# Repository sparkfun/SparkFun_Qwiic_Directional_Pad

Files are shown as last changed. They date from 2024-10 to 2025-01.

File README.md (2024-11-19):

SparkFun Qwiic Directional Pad
========================================

SparkFun Qwiic Directional Pad (https://www.sparkfun.com/products/26851)

[*SparkFun Qwiic Directional Pad (PRT-26851)*](https://www.sparkfun.com/products/26851)

<Basic description of the part.>

Repository Contents
-------------------

* **.github/workflows** - YAML files used for GitHub Actions and GitHub Pages/mkdocs
* **/Firmware** - Example code
* **/Hardware** - KiCad design files (.kicad_pcb, .kicad_sch, .kicad_pro)
* **/docs** - Online documentation files
  * **/assets** - Folder containing all the file assets used for product documentation
    * **/3d_model** - Exported 3D models from KiCad
    * **/board_files** - Copy of design files used for product documentation
    * **/component_documentation** - Datasheets and manuals for hardware components
    * **/img** - Images for product documentation
  * **/github** - Files stating how to contribute and filing issues used for product documentation
  * **/javascript** - Folder containing custom javascript used for product documentation
  * **/stylesheet** - Folder containing CSS files used for product documentation
* **/overrides** - Customization files used for product documentation
  * **/.icons** - Icons used for GitHub used for product documentation
  * **./partials** - Used for product documentation

Documentation
--------------
* **[Library](https://github.com/sparkfun/SparkFun_I2C_Expander_Arduino_Library)** - Arduino library for the Qwiic Directional Pad.
* **[Hookup Guide](https://docs.sparkfun.com/SparkFun_Qwiic_Directional_Pad/)** - Basic hookup guide for the Qwiic Directional Pad.

Product Versions
----------------
* [PRT-26851](https://www.sparkfun.com/products/26851) - v1.1

Version History
---------------
* v1.1 - Initial Release

License Information
-------------------

This product is _**open source**_! 

Please review the LICENSE.md file for license information. 

If you have any questions or concerns on licensing, please contact technical support on our [SparkFun forums](https://forum.sparkfun.com/viewforum.php?f=152).

Distributed as-is; no warranty is given.

- Your friends at SparkFun.

_<COLLABORATION CREDIT>_

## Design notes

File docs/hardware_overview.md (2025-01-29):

In this section, we will highlight the hardware and pins that are broken out on the SparkFun Qwiic Directional Pad. For more information, check out our [Resources and Going Further](../resources/) on the components used on the breakout board.

<div style="text-align: center;">
  <table>
    <tr style="vertical-align:middle;">
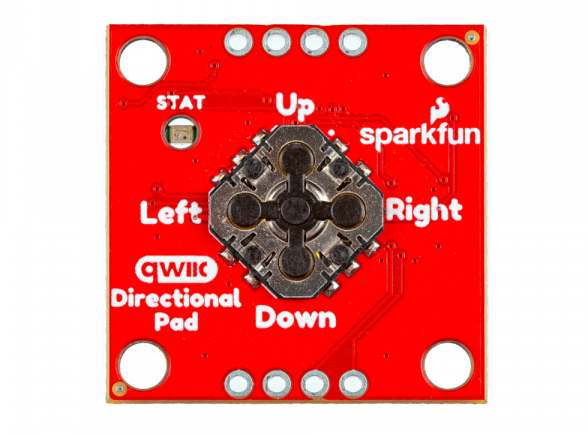
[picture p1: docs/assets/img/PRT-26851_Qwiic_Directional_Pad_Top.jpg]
Top View
     <td style="text-align: center; vertical-align: middle; border: solid 1px #cccccc;"></td>
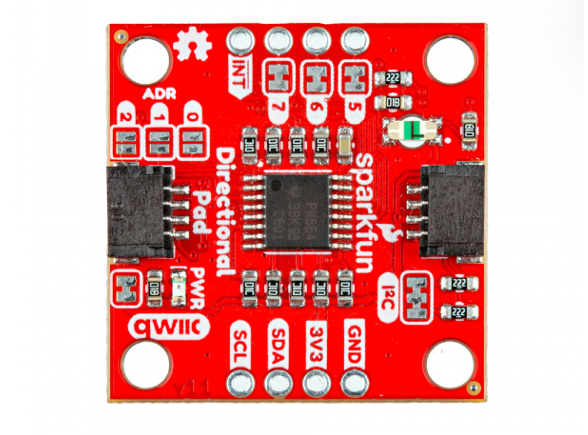
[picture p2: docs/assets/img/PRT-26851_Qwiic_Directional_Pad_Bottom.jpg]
Bottom View
     <td style="text-align: center; vertical-align: middle; border: solid 1px #cccccc;"></td>
    </tr>
    <tr style="vertical-align:middle;">
     <td style="text-align: center; vertical-align: middle; border: solid 1px #cccccc;"><i>Top View</i></td>
     <td style="text-align: center; vertical-align: middle; border: solid 1px #cccccc;"><i>Bottom View</i></td>
    </tr>
  </table>
</div>

### Power

To power the board, you will need **3.3V**. You can connect a Qwiic cable to the Qwiic connector on either side of the board or you can solder directly to the PTHs. Below are the power pins that are broken out on the edge of the board.

* **3V3** &mdash; This pin is the voltage input for the board. The recommended input voltage for this pin is 3.3V.
* **GND** &mdash; Of course, is the common, ground voltage (0V reference) for the system.

<div style="text-align: center;">
  <table>
    <tr style="vertical-align:middle;">
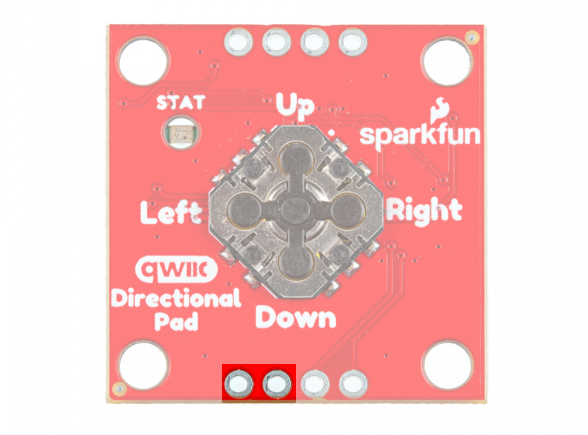
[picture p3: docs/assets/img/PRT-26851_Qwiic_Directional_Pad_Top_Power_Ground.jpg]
Power and Ground Highlighted - Top View
      <td style="text-align: center; vertical-align: middle; border: solid 1px #cccccc;"></td>
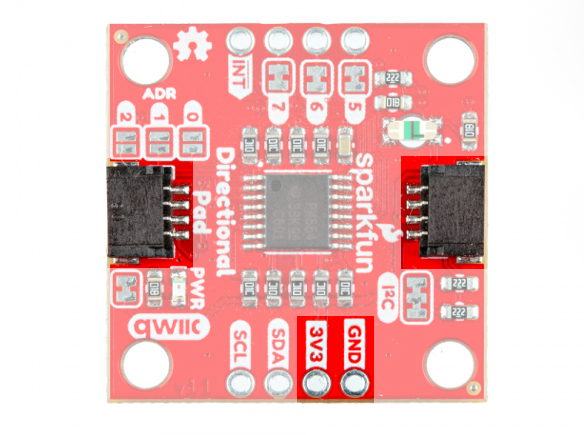
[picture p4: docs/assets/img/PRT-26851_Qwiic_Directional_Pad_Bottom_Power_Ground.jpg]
Power, Ground, and Qwiic Connector Highlighted - Bottom View
     <td style="text-align: center; vertical-align: middle; border: solid 1px #cccccc;"></td>
    </tr>
    <tr style="vertical-align:middle;">
      <td style="text-align: center; vertical-align: middle; border: solid 1px #cccccc;"><i>Power and Ground Highlighted - Top View</i></td>
     <td style="text-align: center; vertical-align: middle; border: solid 1px #cccccc;"><i>Power, Ground, and Qwiic Connector Highlighted - Bottom View</i></td>
    </tr>
  </table>
</div>

### 5-Way Directional Pad

A low profile 5-way directional pad is populated on the top side of the board. These buttons are small! We recommend using your fingernail when pressing down on a button. Each pad includes a momentary push button that is read by the PCA9554 8-bit I<sup>2</sup>C I/O expander that is populated on the bottom of the board.

<div style="text-align: center;">
  <table>
    <tr style="vertical-align:middle;">
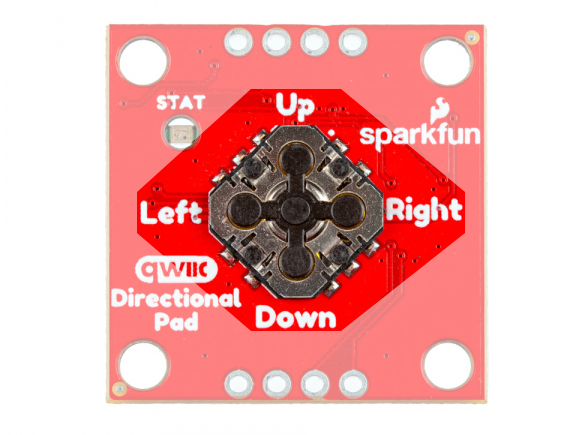
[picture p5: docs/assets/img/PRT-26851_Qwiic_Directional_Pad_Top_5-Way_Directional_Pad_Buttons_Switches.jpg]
5-Way Directional Pad Highlighted - Top View
      <td style="text-align: center; vertical-align: middle; border: solid 1px #cccccc;"></td>
    </tr>
    <tr style="vertical-align:middle;">
      <td style="text-align: center; vertical-align: middle; border: solid 1px #cccccc;"><i>5-Way Directional Pad Highlighted - Top View</i></td>
    </tr>
  </table>
</div>

!!! note
    We recommend pressing only one button at a time! For example, if the UP button is pressed down, it will register the UP button being pressed down first due to the way the condition statements are written in the Arduino code. Once the UP button is released, the board will be able to read another button press. However, if the LEFT button is pressed and then the UP button is pressed, the Qwiic Directional Pad will register the UP button.

### PCA9554 8-bit I<sup>2</sup>C I/O Expander

The TI PCA9554 that is populated on the bottom side of the board is an 8-bit I<sup>2</sup>C I/O expander that enables users to read and write to the following GPIO pins through I<sup>2</sup>C. It is used to read the 5-way directional pad or write to the non-addressable RGB LED. The I<sup>2</sup>C address of the PCA9554 is set to **0x20** by default. By adjusting the jumpers on the back of the board, the alternative address can be any value between _0x21_ to _0x27_.

* **GPIO0** &mdash; GPIO0 is connected to the 5-way directional pad's UP button. A 10k&ohm; pull-up resistor is connected.
* **GPIO1** &mdash; GPIO1 is connected to the 5-way directional pad's DOWN button. A 10k&ohm; pull-up resistor is connected.
* **GPIO2** &mdash; GPIO3 is connected to the 5-way directional pad's RIGHT button. A 10k&ohm; pull-up resistor is connected.
* **GPIO3** &mdash; GPIO4 is connected to the 5-way directional pad's LEFT button. A 10k&ohm; pull-up resistor is connected.
* **GPIO4** &mdash; GPIO4 is connected to the 5-way directional pad's CENTER button. A 10k&ohm; pull-up resistor is connected.
* **GPIO5** &mdash; GPIO5 is connected to the blue LED. The LED can be disconnected if users decide to use a different input to the GPIO5's PTH.
* **GPIO6** &mdash; GPIO6 is connected to the green LED. The LED can be disconnected if users decide to use a different input to the GPIO6's PTH.
* **GPIO7** &mdash; GPIO7 is connected to the red LED. The LED can be disconnected if users decide to use a different input to the GPIO7's PTH.

<div style="text-align: center;">
  <table>
    <tr style="vertical-align:middle;">
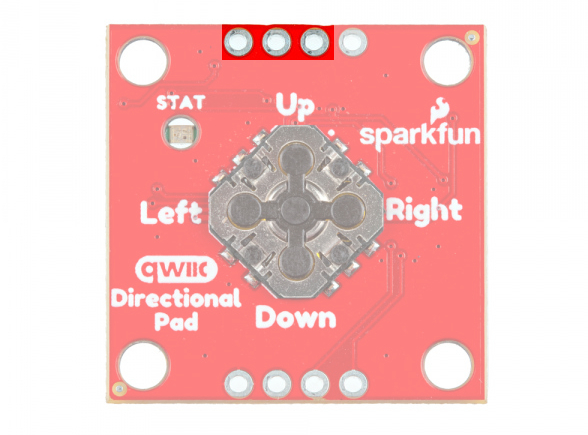
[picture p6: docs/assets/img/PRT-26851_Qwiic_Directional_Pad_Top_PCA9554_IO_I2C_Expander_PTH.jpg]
PCA9554 Highlighted - Top View
      <td style="text-align: center; vertical-align: middle; border: solid 1px #cccccc;"></td>
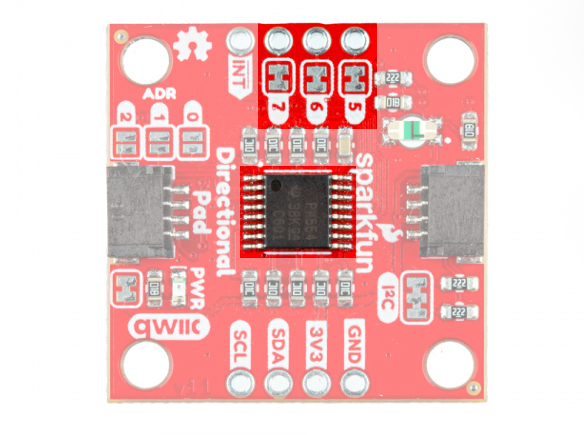
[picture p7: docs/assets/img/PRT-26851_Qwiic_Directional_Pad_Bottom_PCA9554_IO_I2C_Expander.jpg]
PCA9554 Highlighted - Bottom View
      <td style="text-align: center; vertical-align: middle; border: solid 1px #cccccc;"></td>
    </tr>
    <tr style="vertical-align:middle;">
     <td style="text-align: center; vertical-align: middle; border: solid 1px #cccccc;" colspan=2"><i>PCA9554 and Some GPIO Pins Highlighted<br />Top and Bottom View</i></td>
    </tr>
  </table>
</div>

### Qwiic and I<sup>2</sup>C

The board includes two horizontal Qwiic connectors to connect to other Qwiic-enabled I<sup>2</sup>C devices. However, the board still breaks out 0.1"-spaced pins for users who prefer a soldered connection.

* **SCL** &mdash; I<sup>2</sup>C clock on the PCA9554.
* **SDA** &mdash; I<sup>2</sup>C data on the PCA9554.

<div style="text-align: center;">
  <table>
    <tr style="vertical-align:middle;">
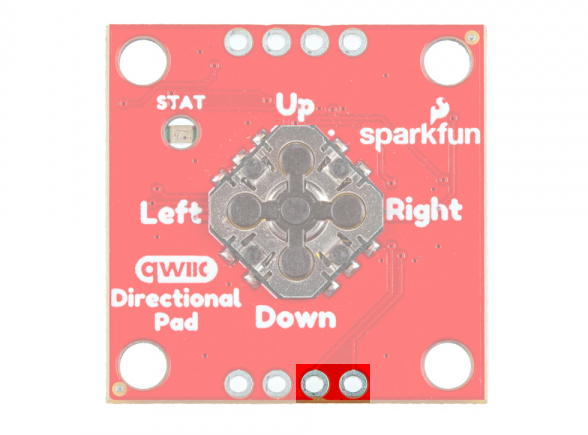
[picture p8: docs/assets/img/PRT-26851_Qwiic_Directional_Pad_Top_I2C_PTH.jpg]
Qwiic Connector, I2C, and PCA9554 Highlighted
     <td style="text-align: center; vertical-align: middle; border: solid 1px #cccccc;"></td>
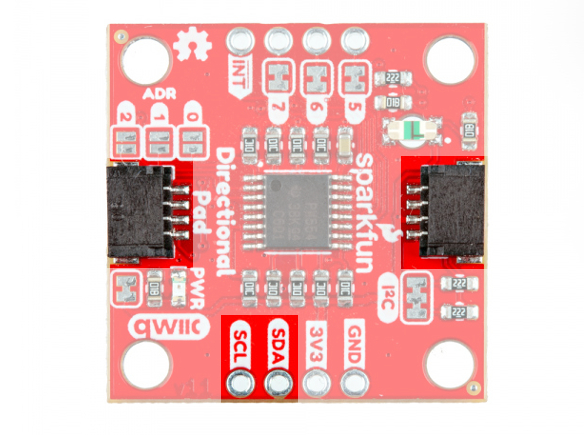
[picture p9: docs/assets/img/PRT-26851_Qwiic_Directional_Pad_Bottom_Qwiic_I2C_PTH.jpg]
Qwiic Connector, I2C, and PCA9554 Highlighted
     <td style="text-align: center; vertical-align: middle; border: solid 1px #cccccc;"></td>
    </tr>
    <tr style="vertical-align:middle;">
     <td style="text-align: center; vertical-align: middle; border: solid 1px #cccccc;"><i>Qwiic Connector, I<sup>2</sup>C, and PCA9554 Highlighted - Top View</i></td>
      <td style="text-align: center; vertical-align: middle; border: solid 1px #cccccc;"><i>I<sup>2</sup>C Highlighted - Bottom View</i></td>
    </tr>
  </table>
</div>

As explained in the previous section, the I<sup>2</sup>C address of the PCA9554 is set to **0x20** by default. By adjusting the jumpers on the back of the board, the alternative address can be any value between _0x21_ to _0x27_. Make sure to check the Jumpers section below for more information.

### Interrupt

The interrupt pin labeled as INT is for users that want to notify a microcontroller that there is a button being pressed down on the 5-way directional pad. This pin is active low.

<div style="text-align: center;">
  <table>
    <tr style="vertical-align:middle;">
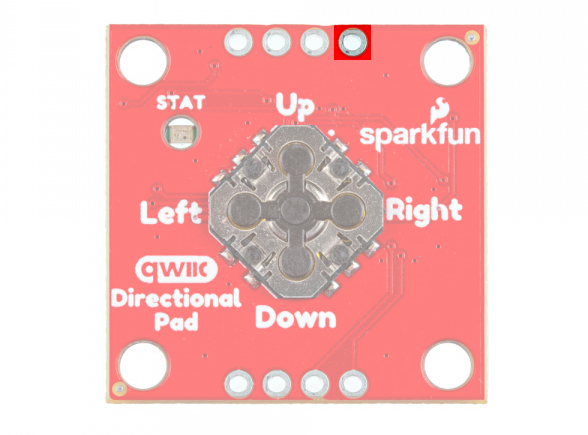
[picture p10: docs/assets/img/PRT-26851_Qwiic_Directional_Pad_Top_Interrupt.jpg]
Interrupt Highlighted - Top View
      <td style="text-align: center; vertical-align: middle; border: solid 1px #cccccc;"></td>
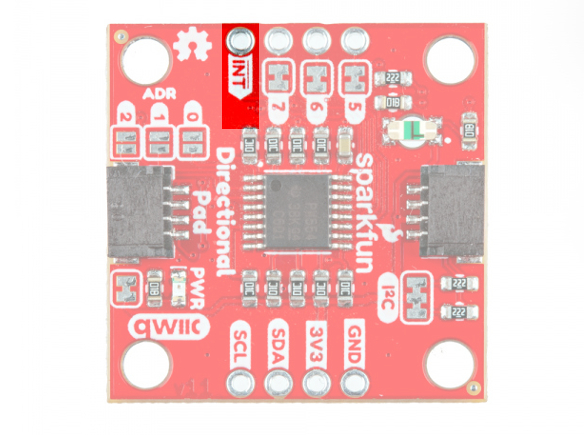
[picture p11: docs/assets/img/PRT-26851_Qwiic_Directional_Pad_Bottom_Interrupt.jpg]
Interrupt Highlighted - Bottom View
      <td style="text-align: center; vertical-align: middle; border: solid 1px #cccccc;"></td>
    </tr>
    <tr style="vertical-align:middle;">
     <td style="text-align: center; vertical-align: middle; border: solid 1px #cccccc;" colspan="2"><i>Interrupt Highlighted - Top and Bottom View</i></td>
    </tr>
  </table>
</div>

### LEDs

The board includes two LEDs on the top and bottom of the board. Both can be disabled with the jumpers on the back of the board.

* **PWR** &mdash; On the bottom side of the board, the power LED indicates when power is available on 3.3V.
* **STAT** &mdash; The status LED is a non-addressable RGB LED that is used to indicate which button is being pressed on the 5-way directional pad. While this is populated on the bottom of the board, it will light up through the hole toward the top side of the board. Each channel can be disabled with the jumper on the back for users that want to connect them to some other input. Note that two colors were not used since there were only 5 buttons available on the directional pad.
<div style="text-align: center;">
    <table>
        <tr>
            <th style="text-align: center; border: solid 1px #cccccc;">Button Press
            </th>
            <th style="text-align: center; border: solid 1px #cccccc;">Color
            </th>
            <th style="text-align: center; border: solid 1px #cccccc;">Red<br />(GPIO7)
            </th>
            <th style="text-align: center; border: solid 1px #cccccc;">Green<br />(GPIO6)
            </th>
            <th style="text-align: center; border: solid 1px #cccccc;">Blue<br />(GPIO5)
            </th>
        </tr>
        <tr>        
            <td style="text-align: center; border: solid 1px #cccccc;">Up
            </td>
            <td style="text-align: center; border: solid 1px #cccccc;">Red
            </td>
            <td style="text-align: center; border: solid 1px #cccccc;">1
            </td>
            <td style="text-align: center; border: solid 1px #cccccc;">0
            </td>
            <td style="text-align: center; border: solid 1px #cccccc;">0
            </td>
        </tr>
        <tr>            
            <td style="text-align: center; border: solid 1px #cccccc;">Down
            </td>   
            <td style="text-align: center; border: solid 1px #cccccc;">Green
            </td>
            <td style="text-align: center; border: solid 1px #cccccc;">0
            </td>
            <td style="text-align: center; border: solid 1px #cccccc;">1
            </td>
            <td style="text-align: center; border: solid 1px #cccccc;">0
            </td>
        </tr>
        <tr>            
            <td style="text-align: center; border: solid 1px #cccccc;">Left
            </td>   
            <td style="text-align: center; border: solid 1px #cccccc;">Magenta
            </td>
            <td style="text-align: center; border: solid 1px #cccccc;">1
            </td>
            <td style="text-align: center; border: solid 1px #cccccc;">0
            </td>
            <td style="text-align: center; border: solid 1px #cccccc;">1
            </td>
        </tr>
        <tr>       
            <td style="text-align: center; border: solid 1px #cccccc;">Right
            </td>        
            <td style="text-align: center; border: solid 1px #cccccc;">Cyan
            </td>
            <td style="text-align: center; border: solid 1px #cccccc;">0
            </td>
            <td style="text-align: center; border: solid 1px #cccccc;">1
            </td>
            <td style="text-align: center; border: solid 1px #cccccc;">1
            </td>
        </tr>
        <tr>       
            <td style="text-align: center; border: solid 1px #cccccc;">Center
            </td>        
            <td style="text-align: center; border: solid 1px #cccccc;">White
            </td>
            <td style="text-align: center; border: solid 1px #cccccc;">1
            </td>
            <td style="text-align: center; border: solid 1px #cccccc;">1
            </td>
            <td style="text-align: center; border: solid 1px #cccccc;">1
            </td>
        </tr>
            <tr><td style="text-align: center; border: solid 1px #cccccc;"><i>No Button Press</i>
            </td>          
            <td style="text-align: center; border: solid 1px #cccccc;">OFF
            </td>
            <td style="text-align: center; border: solid 1px #cccccc;">0
            </td>
            <td style="text-align: center; border: solid 1px #cccccc;">0
            </td>
            <td style="text-align: center; border: solid 1px #cccccc;">0
            </td>
        </tr>
        <tr>
            <tr><td style="text-align: center; border: solid 1px #cccccc;"><i>Not Assigned</i>
            </td>        
            <td style="text-align: center; border: solid 1px #cccccc;">Blue
            </td>
            <td style="text-align: center; border: solid 1px #cccccc;">0
            </td>
            <td style="text-align: center; border: solid 1px #cccccc;">0
            </td>
            <td style="text-align: center; border: solid 1px #cccccc;">1
            </td>
        </tr>
        <tr>
            <tr><td style="text-align: center; border: solid 1px #cccccc;"><i>Not Assigned</i>
            </td>        
            <td style="text-align: center; border: solid 1px #cccccc;">Yellow
            </td>
            <td style="text-align: center; border: solid 1px #cccccc;">1
            </td>
            <td style="text-align: center; border: solid 1px #cccccc;">1
            </td>
            <td style="text-align: center; border: solid 1px #cccccc;">0
            </td>
        </tr>
    </table>
</div>

<div style="text-align: center;">
  <table>
    <tr style="vertical-align:middle;">
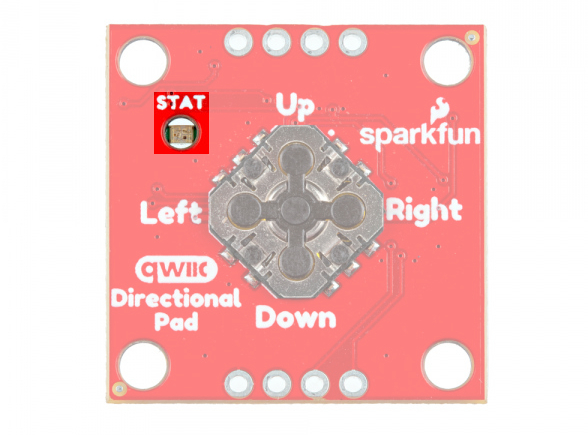
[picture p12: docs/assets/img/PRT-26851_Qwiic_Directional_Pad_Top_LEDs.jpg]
LEDs Highlighted
      <td style="text-align: center; vertical-align: middle; border: solid 1px #cccccc;"></td>
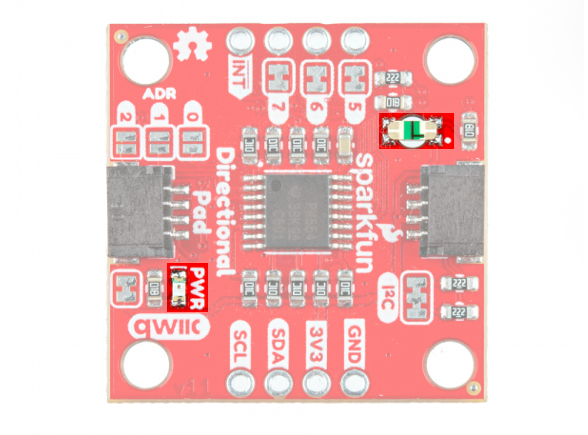
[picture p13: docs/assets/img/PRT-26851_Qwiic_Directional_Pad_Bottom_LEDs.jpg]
LEDs Highlighted
      <td style="text-align: center; vertical-align: middle; border: solid 1px #cccccc;"></td>
    </tr>
    <tr style="vertical-align:middle;">
     <td style="text-align: center; vertical-align: middle; border: solid 1px #cccccc;" colspan="2"><i>LEDs Highlighted Top and Bottom View</i></td>
    </tr>
  </table>
</div>

### Jumpers

!!!note
    If this is your first time working with jumpers, check out the [How to Work with Jumper Pads and PCB Traces](https://learn.sparkfun.com/tutorials/how-to-work-with-jumper-pads-and-pcb-traces/all) tutorial for more information.

The back of the board includes jumpers to configure the board.

* **PWR** &mdash; By default, the power jumper connects the LED to the output's 3.3V pin. Cutting this trace disables the LED.
* **7** &mdash; By default, this jumper is closed. Cutting this jumper will disconnect GPIO7 and the red channel from the RGB LED. Once disabled, GPIO7 is available for users that want to connect them to some other input.
* **6** &mdash; By default, this jumper is closed. Cutting this jumper will disconnect GPIO6 and the green channel from the RGB LED. Once disabled, GPIO6 is available for users that want to connect them to some other input.
* **5** &mdash; By default, this jumper is closed. Cutting this jumper will disconnect GPIO5 and the blue channel from the RGB LED. Once disabled, GPIO5 is available for users that want to connect them to some other input.
* **I<sup>2</sup>C** &mdash; By default, this three-pad jumper is closed. The three way jumper labeled I<sup>2</sup>C connects 3.3V to two 2.2k&ohm; pull-up resistors and to the I<sup>2</sup>C data and clock lines. If multiple devices are connected to the bus with the pull-up resistors enabled, the parallel equivalent resistance will create too strong of a pull-up for the bus to operate correctly. As a general rule of thumb, [disable all but one pair of pull-up resistors](https://learn.sparkfun.com/tutorials/i2c/all#i2c-at-the-hardware-level) if multiple devices are connected to the bus.
* **ADR**  &mdash; By default, the three jumpers **0**, **1**, and **2** are open. These set the I<sup>2</sup>C address of the Qwiic Directional Pad. Adding a solder blob will close the jumper and set the jumper as a `1`. Below shows the table needed to configure the three jumpers to achieve the desired I<sup>2</sup>C address.
<div style="text-align: center;">
    <table>
        <tr>
            <th style="text-align: center; border: solid 1px #cccccc;">I<sup>2</sup>C Address
            </th>
            <th style="text-align: center; border: solid 1px #cccccc;">ADR2<br/> (Jumper <b>2</b>)
            </th>
            <th style="text-align: center; border: solid 1px #cccccc;">ADR1<br/> (Jumper <b>1</b>)
            </th>
            <th style="text-align: center; border: solid 1px #cccccc;">ADR0<br/>(Jumper <b>0</b>)
            </th>
        </tr>
        <tr>        
            <td style="text-align: center; border: solid 1px #cccccc;">0x20
            </td>
            <td style="text-align: center; border: solid 1px #cccccc;">0
            </td>
            <td style="text-align: center; border: solid 1px #cccccc;">0
            </td>
            <td style="text-align: center; border: solid 1px #cccccc;">0
            </td>
        </tr>
        <tr>        
            <td style="text-align: center; border: solid 1px #cccccc;">0x21
            </td>
            <td style="text-align: center; border: solid 1px #cccccc;">0
            </td>
            <td style="text-align: center; border: solid 1px #cccccc;">0
            </td>
            <td style="text-align: center; border: solid 1px #cccccc;">1
            </td>
        </tr>
        <tr>        
            <td style="text-align: center; border: solid 1px #cccccc;">0x22
            </td>
            <td style="text-align: center; border: solid 1px #cccccc;">0
            </td>
            <td style="text-align: center; border: solid 1px #cccccc;">1
            </td>
            <td style="text-align: center; border: solid 1px #cccccc;">0
            </td>
        </tr>
        <tr>        
            <td style="text-align: center; border: solid 1px #cccccc;">0x23
            </td>
            <td style="text-align: center; border: solid 1px #cccccc;">0
            </td>
            <td style="text-align: center; border: solid 1px #cccccc;">1
            </td>
            <td style="text-align: center; border: solid 1px #cccccc;">1
            </td>
        </tr>
        <tr>        
            <td style="text-align: center; border: solid 1px #cccccc;">0x24
            </td>
            <td style="text-align: center; border: solid 1px #cccccc;">1
            </td>
            <td style="text-align: center; border: solid 1px #cccccc;">0
            </td>
            <td style="text-align: center; border: solid 1px #cccccc;">0
            </td>
        </tr>
        <tr>        
            <td style="text-align: center; border: solid 1px #cccccc;">0x25
            </td>
            <td style="text-align: center; border: solid 1px #cccccc;">1
            </td>
            <td style="text-align: center; border: solid 1px #cccccc;">0
            </td>
            <td style="text-align: center; border: solid 1px #cccccc;">1
            </td>
        </tr>
        <tr>        
            <td style="text-align: center; border: solid 1px #cccccc;">0x26
            </td>
            <td style="text-align: center; border: solid 1px #cccccc;">1
            </td>
            <td style="text-align: center; border: solid 1px #cccccc;">1
            </td>
            <td style="text-align: center; border: solid 1px #cccccc;">0
            </td>
        </tr>
        <tr>        
            <td style="text-align: center; border: solid 1px #cccccc;">0x27
            </td>
            <td style="text-align: center; border: solid 1px #cccccc;">1
            </td>
            <td style="text-align: center; border: solid 1px #cccccc;">1
            </td>
            <td style="text-align: center; border: solid 1px #cccccc;">1
            </td>
        </tr>
    </table>
</div>

<div style="text-align: center;">
  <table>
    <tr style="vertical-align:middle;">
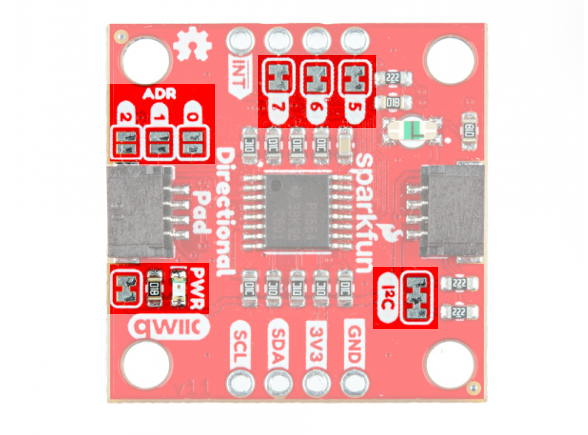
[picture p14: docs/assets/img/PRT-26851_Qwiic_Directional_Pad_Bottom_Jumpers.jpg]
Jumpers Highlighted - Bottom View
     <td style="text-align: center; vertical-align: middle; border: solid 1px #cccccc;"></td>
    </tr>
    <tr style="vertical-align:middle;">
     <td style="text-align: center; vertical-align: middle; border: solid 1px #cccccc;"><i>Jumpers Highlighted<br />Bottom View</i></td>
    </tr>
  </table>
</div>

### 3D Model

A 3D model of the board and components was exported to a STEP file using KiCad.

<!-- Import the component -->
<script type="module" src="https://ajax.googleapis.com/ajax/libs/model-viewer/3.5.0/model-viewer.min.js"></script>

<div style="text-align: center;">
    <model-viewer src="../assets/3d_model/SparkFun_Qwiic_Directional_Pad_3D_Model.glb" camera-controls poster="../assets/3d_model/SparkFun_Qwiic_Directional_Pad_3D_Image.png" environment-image="legacy" shadow-intensity="1.58" exposure="0.64" shadow-softness="0.24" tone-mapping="neutral" camera-orbit="-46.67deg 57.14deg 153.3m" field-of-view="30deg" style="width: 750px; height: 500px;">
    </model-viewer>
</div>
<br />
<div style="text-align: center">
    <a href="../assets/3d_model/SparkFun_Qwiic_Directional_Pad_3D_Model.step" target="stp_file" class="md-button">Click Here for the STEP File</a>
</div>

### Board Dimensions

The board is 1.0" x 1.0" (25.4mm x 25.4mm). There are 2x mounting holes. You can use 4-40 standoffs to mount the board to a panel or enclosure.

<div style="text-align: center;">
  <table>
    <tr style="vertical-align:middle;">
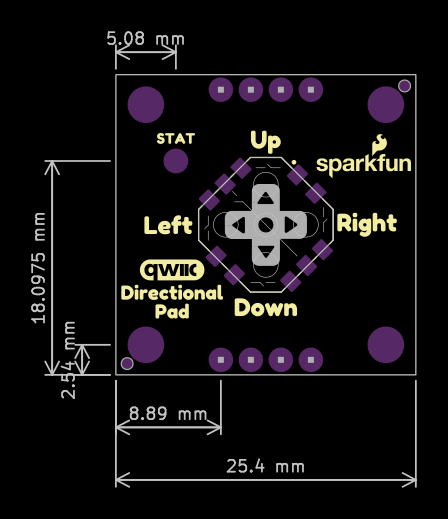
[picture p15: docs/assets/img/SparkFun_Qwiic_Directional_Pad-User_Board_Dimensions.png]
Board Dimensions
     <td style="text-align: center; vertical-align: middle; border: solid 1px #cccccc;"></td>
    </tr>
    <tr style="vertical-align:middle;">
     <td style="text-align: center; vertical-align: middle; border: solid 1px #cccccc;"><i>Board Dimensions</i></td>
    </tr>
  </table>
</div>

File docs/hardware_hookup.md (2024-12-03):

In this section, we will go over how to connect to the Qwiic Directional Pad.

### Connecting Via Qwiic

Insert a Qwiic cable between your Arduino microcontroller and the Qwiic Directional Pad. In this case, we used the SparkFun IoT RedBoard - ESP32 Development Board for the Arduino microcontroller. When ready, connect a USB cable to the Arduino to program, power, and view serial messages.

<div style="text-align: center;">
  <table>
    <tr style="vertical-align:middle;">
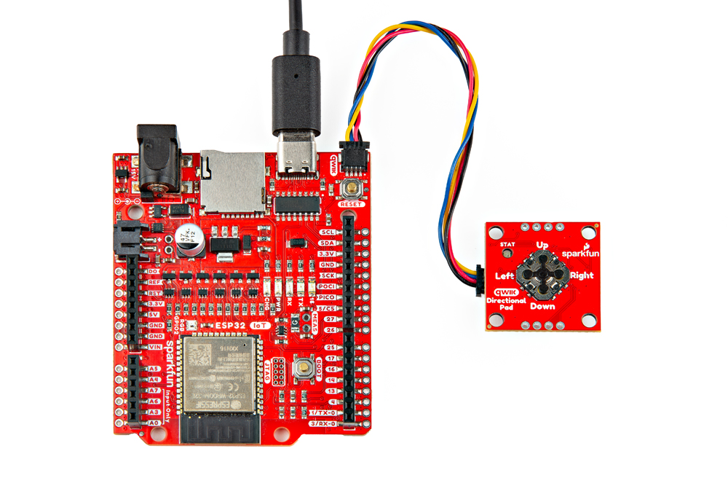
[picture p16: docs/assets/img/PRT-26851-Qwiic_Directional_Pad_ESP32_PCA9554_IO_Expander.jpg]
IoT RedBoard - ESP32 and Qwiic Directional Pad Connectedvia Qwiic
     <td style="text-align: center; vertical-align: middle; border: solid 1px #cccccc;"></td>
    </tr>
    <tr style="vertical-align:middle;">
     <td style="text-align: center; vertical-align: middle; border: solid 1px #cccccc;"><i>IoT RedBoard - ESP32 and Qwiic Directional Pad Connected via Qwiic</i></td>
    </tr>
  </table>
</div>

### Connecting via PTH

For temporary connections to the PTHs, you could use IC hooks to test out the pins. However, you'll need to solder headers or wires of your choice to the board for a secure connection. You can choose between a combination of [header pins and jumper wires](https://learn.sparkfun.com/tutorials/how-to-solder-through-hole-soldering/all), or [stripping wire and soldering the wire](https://learn.sparkfun.com/tutorials/working-with-wire/all) directly to the board.

<div class="grid cards col-2" markdown>

-   <a href="https://learn.sparkfun.com/tutorials/how-to-solder-through-hole-soldering/all">
      <figure markdown>
        How to Solder: Through Hole Soldering
      </figure>
    </a>

    ---

    <a href="https://learn.sparkfun.com/tutorials/how-to-solder-through-hole-soldering/all">
      <b>How to Solder: Through Hole Soldering</b>
    </a>
<!-- ----------WHITE SPACE BETWEEN GRID CARDS---------- -->

-   <a href="https://learn.sparkfun.com/tutorials/working-with-wire/all">
      <figure markdown>
        Working with Wire
      </figure>
    </a>

    ---

    <a href="https://learn.sparkfun.com/tutorials/working-with-wire/all">
      <b>Working with Wire</b>
    </a>
<!-- ----------WHITE SPACE BETWEEN GRID CARDS---------- -->
</div>

### Interrupt

For users that want to notify the microcontroller that there is a button press, you could connect the INT pin to one of the Arduino's interrupts. In this case, we connected the Directional Pad's INT pin to IoT RedBoard's pin 4.

<div style="text-align: center;">
  <table>
    <tr style="vertical-align:middle;">
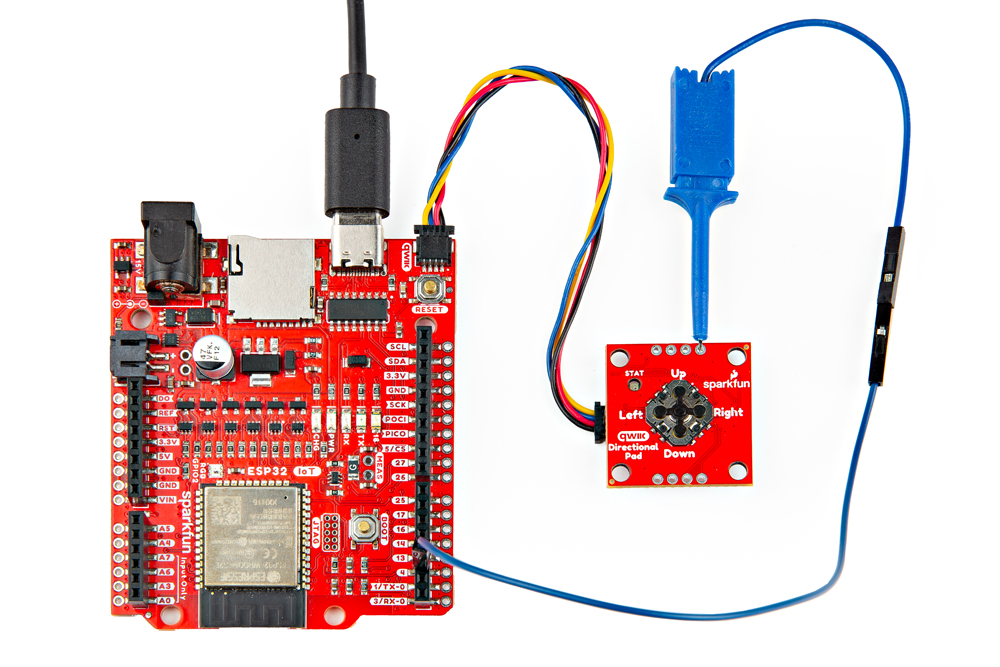
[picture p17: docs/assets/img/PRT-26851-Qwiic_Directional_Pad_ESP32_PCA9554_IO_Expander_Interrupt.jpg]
IoT RedBoard - ESP32 and Qwiic Directional Pad Connected via Qwiic and Interrupt Pin
     <td style="text-align: center; vertical-align: middle; border: solid 1px #cccccc;"></td>
    </tr>
    <tr style="vertical-align:middle;">
     <td style="text-align: center; vertical-align: middle; border: solid 1px #cccccc;"><i>IoT RedBoard - ESP32 and Qwiic Directional Pad Connected via Qwiic and Interrupt Pin</i></td>
    </tr>
  </table>
</div>

!!! note
    Example 3 from the SparkFun I2C Expander Arduino Library uses the IoT RedBoard - ESP32's pin `14` for the interrupt. The example in this tutorial is slightly different and uses pin `4` for the interrupt.

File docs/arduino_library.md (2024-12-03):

!!! arduino
    This example assumes you are using the latest version of the Arduino IDE on your desktop. If this is your first time using Arduino IDE, library, or board add-on, please review the following tutorials.

    - [Installing the Arduino IDE](https://learn.sparkfun.com/tutorials/installing-arduino-ide)
    - [Installing an Arduino Library](https://learn.sparkfun.com/tutorials/installing-an-arduino-library)
    - [Installing Board Definitions in the Arduino IDE](https://learn.sparkfun.com/tutorials/installing-board-definitions-in-the-arduino-ide)

!!! note
    If you've never connected an CH340 device to your computer before, you may need to install drivers for the USB-to-serial converter. Check out our section on "[How to Install CH340 Drivers](https://learn.sparkfun.com/tutorials/how-to-install-ch340-drivers)" for help with the installation.

    - [How to Install CH340 Drivers](https://learn.sparkfun.com/tutorials/how-to-install-ch340-drivers/all)

SparkFun has written [basic examples for the Qwiic Directional Pad](https://github.com/sparkfun/SparkFun_Qwiic_Directional_Pad/tree/main/Firmware) and is provided in the GitHub Hardware repository.

<div style="text-align: center">
    <a href="https://github.com/sparkfun/SparkFun_Qwiic_Directional_Pad/tree/main/Firmware" class="md-button">SparkFun Qwiic Directional Pad: Examples</a>
</div>

You will need the SparkFun I2C Expander Arduino Library to work with the Qwiic Directional Pad's basic examples. You can obtain this library through the Arduino Library Manager by searching for "**SparkFun I2C Expander Arduino Library**". Find the one written by SparkFun Electronics and install the latest version. Users who prefer to manually install the library can get it from the [GitHub Repository](https://github.com/sparkfun/SparkFun_I2C_Expander_Arduino_Library) or download the .ZIP by clicking the button below:

<div style="text-align: center">
    <a href="https://github.com/sparkfun/SparkFun_I2C_Expander_Arduino_Library/archive/refs/heads/main.zip" class="md-button">SparkFun Qwiic I2C Expander Arduino Library (ZIP)</a>
</div>

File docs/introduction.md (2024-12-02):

The [SparkFun Qwiic Directional Pad](https://www.sparkfun.com/products/26851) adds a 5-way directional pad to your I<sup>2</sup>C bus! When connected to a microcontroller, press down on the directional pad (up, down, left, right, or center) to provide additional input for your application. The built-in RGB status LED provides visual feedback indicating which button is pressed.

<div class="grid cards" style="width:500px; margin: 0 auto;" markdown>
<!-- ----------WHITE SPACE BETWEEN PRODUCTS---------- -->
-   <a href="https://www.sparkfun.com/products/26851">
      <figure markdown>
        SparkFun Qwiic Directional Pad
      </figure>
    </a>

    ---

    <a href="https://www.sparkfun.com/products/26851">
      <b>SparkFun Qwiic Directional Pad</b>
      <br />
      PRT-26851
      <br />
      <center>[Purchase from SparkFun :fontawesome-solid-cart-plus:](https://www.sparkfun.com/products/26851){ .md-button .md-button--primary }</center>
    </a>
</div>

In this tutorial, we'll go over the hardware and how to hookup the SparkFun Qwiic Directional Pad to an Arduino. We will also go over some Arduino examples to get started.

### Required Materials

To follow along with this tutorial, you will need the following materials. You may not need everything though depending on what you have. Add it to your cart, read through the guide, and adjust the cart as necessary.

<div class="grid cards col-4" markdown>
<!-- ----------WHITE SPACE BETWEEN PRODUCTS---------- -->
-   <a href="https://www.sparkfun.com/products/15424">
      <figure markdown>
        Reversible USB A to C Cable - 2m
      </figure>
    </a>

    ---

    <a href="https://www.sparkfun.com/products/15424">
      <b>Reversible USB A to C Cable - 2m</b>
      <br />
      CAB-15424
    </a>
<!-- ----------WHITE SPACE BETWEEN PRODUCTS---------- -->
-   <a href="https://www.sparkfun.com/products/19177">
      <figure markdown>
        SparkFun IoT RedBoard - ESP32 Development Board
      </figure>
    </a>

    ---

    <a href="https://www.sparkfun.com/products/19177">
      <b>SparkFun IoT RedBoard - ESP32 Development Board</b>
      <br />
      WRL-19177
    </a>
<!-- ----------WHITE SPACE BETWEEN PRODUCTS---------- -->
-   <a href="https://www.sparkfun.com/products/26851">
      <figure markdown>
        SparkFun Qwiic Directional Pad
      </figure>
    </a>

    ---

    <a href="https://www.sparkfun.com/products/26851">
      <b>SparkFun Qwiic Directional Pad</b>
      <br />
      PRT-26784
    </a>
<!-- ----------WHITE SPACE BETWEEN PRODUCTS---------- -->
-   <a href="https://www.sparkfun.com/products/14427">
      <figure markdown>
        Qwiic Cable - 100mm
      </figure>
    </a>

    ---

    <a href="https://www.sparkfun.com/products/14427">
      <b>Qwiic Cable - 100mm</b>
      <br>
      PRT-14427
    </a>
<!-- ----------WHITE SPACE BETWEEN PRODUCTS---------- -->
</div>

### Qwiic Cables

For those that want to take advantage of the Qwiic connector, you'll want to grab a Qwiic cable. There are a variety of other cable lengths available in the SparkFun catalog to choose from.

<div class="grid cards col-4" markdown>

-   <a href="https://www.sparkfun.com/products/15081">
      <figure markdown>
        SparkFun Qwiic Cable Kit
      </figure>
    </a>

    ---

    <a href="https://www.sparkfun.com/products/15081">
      <b>SparkFun Qwiic Cable Kit</b>
      <br />
      KIT-15081
    </a>
<!-- ----------WHITE SPACE BETWEEN PRODUCTS---------- -->
-   <a href="https://www.sparkfun.com/products/14427">
      <figure markdown>
        Qwiic Cable - 100mm
      </figure>
    </a>

    ---

    <a href="https://www.sparkfun.com/products/14427">
      <b>Qwiic Cable - 100mm</b>
      <br>
      PRT-14427
    </a>
<!-- ----------WHITE SPACE BETWEEN PRODUCTS---------- -->
-   <a href="https://www.sparkfun.com/products/14429">
      <figure markdown>
        Qwiic Cable - 500mm
      </figure>
    </a>

    ---

    <a href="https://www.sparkfun.com/products/14429">
      <b>Qwiic Cable - 500mm</b>
      <br />
      PRT-14429
    </a>
<!-- ----------WHITE SPACE BETWEEN PRODUCTS---------- -->
-   <a href="https://www.sparkfun.com/products/14425">
      <figure markdown>
        Qwiic Cable - Breadboard Jumper (4-pin)
      </figure>
    </a>

    ---

    <a href="https://www.sparkfun.com/products/14425">
      <b>Qwiic Cable - Breadboard Jumper (4-pin)</b>
      <br />
      PRT-14425
    </a>
<!-- ----------WHITE SPACE BETWEEN PRODUCTS---------- -->
</div>

### Tools _(Optional)_

For users connecting to the plated through holes, you will need a soldering iron, solder, and [general soldering accessories](https://www.sparkfun.com/categories/49).

<div class="grid cards col-4" markdown>

-   <a href="https://www.sparkfun.com/products/24063">
      <figure markdown>
        PINECIL Soldering Iron Kit
      </figure>
    </a>

    ---

    <a href="https://www.sparkfun.com/products/24063">
      <b>PINECIL Soldering Iron Kit</b>
      <br />
      TOL-24063
    </a>
<!-- ----------WHITE SPACE BETWEEN PRODUCTS---------- -->
-   <a href="https://www.sparkfun.com/products/9163">
      <figure markdown>
        Solder Lead Free - 15-gram Tube
      </figure>
    </a>

    ---

    <a href="https://www.sparkfun.com/products/9163">
      <b>Solder Lead Free - 15-gram Tube</b>
      <br>
      TOL-09163
    </a>
<!-- ----------WHITE SPACE BETWEEN PRODUCTS---------- -->
-   <a href="https://www.sparkfun.com/products/11375">
      <figure markdown>
        Hook-Up Wire - Assortment (Stranded, 22 AWG)
      </figure>
    </a>

    ---

    <a href="https://www.sparkfun.com/products/11375">
      <b>Hook-Up Wire - Assortment (Stranded, 22 AWG)</b>
      <br />
      PRT-11375
    </a>
<!-- ----------WHITE SPACE BETWEEN PRODUCTS---------- -->
-   <a href="https://www.sparkfun.com/products/12630">
      <figure markdown>
        Wire Strippers - 30AWG (Hakko)
      </figure>
    </a>

    ---

    <a href="https://www.sparkfun.com/products/12630">
      <b>Wire Strippers - 30AWG (Hakko)</b>
      <br />
      TOL-12630
    </a>
<!-- ----------WHITE SPACE BETWEEN PRODUCTS---------- -->
-   <a href="https://www.sparkfun.com/products/11952">
      <figure markdown>
        Flush Cutters - Hakko
      </figure>
    </a>

    ---

    <a href="https://www.sparkfun.com/products/11952">
      <b>Flush Cutters - Hakko</b>
      <br />
      TOL-11952
    </a>
<!-- ----------WHITE SPACE BETWEEN PRODUCTS---------- -->
-   <a href="https://www.sparkfun.com/products/12966">
      <figure markdown>
        Digital Multimeter - Basic
      </figure>
    </a>

    ---

    <a href="https://www.sparkfun.com/products/12966">
      <b>Digital Multimeter - Basic</b>
      <br />
      TOL-12966
    </a>
<!-- ----------WHITE SPACE BETWEEN PRODUCTS---------- -->
</div>

### Prototyping Accessories  _(Optional)_

Depending on your setup, you may want to use IC hooks for a temporary connection. However, you will want to solder header pins to connect devices to the plated through holes for a secure connection.

<div class="grid cards col-4" markdown>

-   <a href="https://www.sparkfun.com/products/12002">
      <figure markdown>
        Breadboard - Self-Adhesive (White)
      </figure>
    </a>

    ---

    <a href="https://www.sparkfun.com/products/12002">
      <b>Breadboard - Self-Adhesive (White)</b>
      <br />
      PRT-12002
    </a>
<!-- ----------WHITE SPACE BETWEEN PRODUCTS---------- -->
-   <a href="https://www.sparkfun.com/products/9741">
      <figure markdown>
        IC Hook with Pigtail
      </figure>
    </a>

    ---

    <a href="https://www.sparkfun.com/products/9741">
      <b>IC Hook with Pigtail</b>
      <br>
      CAB-09741
    </a>
<!-- ----------WHITE SPACE BETWEEN PRODUCTS---------- -->
-   <a href="https://www.sparkfun.com/products/553">
      <figure markdown>
        Break Away Male Headers - Right Angle
      </figure>
    </a>

    ---

    <a href="https://www.sparkfun.com/products/553">
      <b>Break Away Male Headers - Right Angle</b>
      <br />
      PRT-00553
    </a>
<!-- ----------WHITE SPACE BETWEEN PRODUCTS---------- -->
-   <a href="https://www.sparkfun.com/products/115">
      <figure markdown>
        Female Headers
      </figure>
    </a>

    ---

    <a href="https://www.sparkfun.com/products/115">
      <b>Female Headers</b>
      <br />
      PRT-00115
    </a>
<!-- ----------WHITE SPACE BETWEEN PRODUCTS---------- -->
-   <a href="https://www.sparkfun.com/products/8431">
      <figure markdown>
        Jumper Wires Premium 6
      <br />
      PRT-08431
    </a>
<!-- ----------WHITE SPACE BETWEEN PRODUCTS---------- -->
-   <a href="https://www.sparkfun.com/products/9140">
      <figure markdown>
        Jumper Wires Premium 6
      <br />
      PRT-09140
    </a>
<!-- ----------WHITE SPACE BETWEEN PRODUCTS---------- -->
</div>

### Suggested Reading

If you aren't familiar with the Qwiic Connection System, we recommend reading [here for an overview](https://www.sparkfun.com/qwiic).

<div style="text-align: center">
  <table style="border-style:none">
    <tr>
     <td style="text-align: center; vertical-align: middle;">
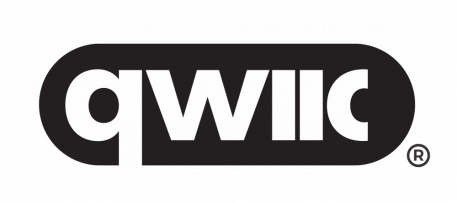
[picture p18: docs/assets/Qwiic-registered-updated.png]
Qwiic Connection System Click to learn more about the Qwiic Connection System!
     <div style="text-align: center">
     </div>
    </td>
    </tr>
    <tr>
      <td style="text-align: center; vertical-align: middle;"><div style="text-align: center"><i><a href="https://www.sparkfun.com/qwiic">Qwiic Connection System</a></i></div></td>
    </tr>
  </table>
</div>

If you aren’t familiar with the following concepts, we also recommend checking out a few of these tutorials before continuing.

<div class="grid cards col-4" markdown>
<!-- ----------WHITE SPACE BETWEEN GRID CARDS---------- -->
-   <a href="https://learn.sparkfun.com/tutorials/installing-arduino-ide">
      <figure markdown>
        Installing Arduino IDE
      </figure>
    </a>

    ---

    <a href="https://learn.sparkfun.com/tutorials/installing-arduino-ide">
      <b>Installing Arduino IDE</b>
    </a>
<!-- ----------WHITE SPACE BETWEEN GRID CARDS---------- -->
-   <a href="https://learn.sparkfun.com/tutorials/iot-redboard-esp32-development-board-hookup-guide">
      <figure markdown>
        IoT RedBoard ESP32 Development Board Hookup Guide
      </figure>
    </a>

    ---

    <a href="https://learn.sparkfun.com/tutorials/iot-redboard-esp32-development-board-hookup-guide">
      <b>IoT RedBoard ESP32 Development Board Hookup Guide</b>
    </a>
<!-- ----------WHITE SPACE BETWEEN GRID CARDS---------- -->
-   <a href="https://learn.sparkfun.com/tutorials/installing-board-definitions-in-the-arduino-ide">
      <figure markdown>
        Installing Board Definitions in the Arduino IDE
      </figure>
    </a>

    ---

    <a href="https://learn.sparkfun.com/tutorials/installing-board-definitions-in-the-arduino-ide">
      <b>Installing Board Definitions in the Arduino IDE</b>
    </a>
<!-- ----------WHITE SPACE BETWEEN GRID CARDS---------- -->
-   <a href="https://learn.sparkfun.com/tutorials/how-to-install-ch340-drivers/all">
      <figure markdown>
        How to Install CH340 Drivers
      </figure>
    </a>

    ---

    <a href="https://learn.sparkfun.com/tutorials/how-to-install-ch340-drivers/all">
      <b>How to Install CH340 Drivers</b>
    </a>
<!-- ----------WHITE SPACE BETWEEN GRID CARDS---------- -->
-   <a href="https://learn.sparkfun.com/tutorials/processor-interrupts-with-arduino/">
      <figure markdown>
        Processor Interrupts with Arduino
      </figure>
    </a>

    ---

    <a href="https://learn.sparkfun.com/tutorials/processor-interrupts-with-arduino/">
      <b>Processor Interrupts with Arduino</b>
    </a>
<!-- ----------WHITE SPACE BETWEEN GRID CARDS---------- -->
-   <a href="https://learn.sparkfun.com/tutorials/logic-levels">
      <figure markdown>
        Logic Levels
      </figure>
    </a>

    ---

    <a href="https://learn.sparkfun.com/tutorials/logic-levels">
      <b>Logic Levels</b>
    </a>
<!-- ----------WHITE SPACE BETWEEN GRID CARDS---------- -->
</div>

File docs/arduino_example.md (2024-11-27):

Now that we have our library and board add-on installed, we can start experimenting with the breakout board. For the scope of this tutorial, we will highlight the examples provided in the GitHub hardware repo to get started.

### Example 1: Read Buttons, Write LEDs

From your downloads, open the example labeled as **Example1-ReadButtons_WriteLEDs.ino**. This example reads the button presses and writes to the non-addressable LED using the PCA9554 I/O I<sup>2</sup>C Expander.

For users using an Arduino microcontroller, select your board in the Tools menu (in our case the **SparkFun ESP32 IoT RedBoard**) and the correct Port it enumerated on.

You can also copy or paste the code as shown below. Then click "Upload".

``` c++
/*
  Using the Qwiic Directional Pad
  By: Nathan Seidle
  SparkFun Electronics
  Date: October 8th, 2024

  License: This code is public domain but you buy me a beer if you use this and we meet someday (Beerware license).

  Feel like supporting our work? Buy a board from SparkFun!
  https://www.sparkfun.com/products/14733

  This example demonstrates how to use pinMode and digitalRead/Write to read the directional pad and turn
  on/off the RGB LED channels.

  Hardware Connections:
  Plug the Qwiic board to your Arduino/ESP32 or other
  Press the buttons
  Watch each LED turn on one-at-a-time
*/

#include <SparkFun_I2C_Expander_Arduino_Library.h> // Click here to get the library: http://librarymanager/All#SparkFun_I2C_Expander_Arduino_Library

SFE_PCA95XX io; // Defaults to the PCA9554 at I2C address 0x20

int buttonUp = 0;
int buttonDown = 1;
int buttonRight = 2;
int buttonLeft = 3;
int buttonCenter = 4;
int ledBlue = 5;
int ledGreen = 6;
int ledRed = 7;

void setup()
{
  Serial.begin(115200);
  delay(250);
  Serial.println("Qwiic Directional Pad Example");

  Wire.begin();

  // Initialize the PCA9554, default address = 0x20
  if (io.begin() == false) //Device Address, Number of GPIO
  {
    Serial.println("PCA9554 not detected. Please check wiring. Freezing...");
    while (1)
      ;
  }

  io.pinMode(buttonUp, INPUT);
  io.pinMode(buttonDown, INPUT);
  io.pinMode(buttonLeft, INPUT);
  io.pinMode(buttonRight, INPUT);
  io.pinMode(buttonCenter, INPUT);
  io.pinMode(ledRed, OUTPUT);
  io.pinMode(ledGreen, OUTPUT);
  io.pinMode(ledBlue, OUTPUT);

  redOff();
  greenOff();
  blueOff();

  Serial.println("Qwiic Directional Pad online!");
}

void loop()
{
  Serial.print("Button: ");

  if (io.digitalRead(buttonUp) == LOW)
  {
    Serial.print("Up");
    redOn();
    greenOff();
    blueOff();
  }
  else if (io.digitalRead(buttonDown) == LOW)
  {
    Serial.print("Down");
    redOff();
    greenOn();
    blueOff();
  }
  else if (io.digitalRead(buttonLeft) == LOW)
  {
    Serial.print("Left");
    redOn();
    greenOff();
    blueOn();
  }
  else if (io.digitalRead(buttonRight) == LOW)
  {
    Serial.print("Right");
    redOff();
    greenOn();
    blueOn();
  }
  else if (io.digitalRead(buttonCenter) == LOW)
  {
    Serial.print("Center");
    redOn();
    greenOn();
    blueOn();
  }
  else
  {
    Serial.print(" None");
    redOff();
    greenOff();
    blueOff();
  }
  Serial.println();

  delay(100);
}

void redOn()
{
  io.digitalWrite(ledRed, LOW);
}
void redOff()
{
  io.digitalWrite(ledRed, HIGH);
}
void greenOn()
{
  io.digitalWrite(ledGreen, LOW);
}
void greenOff()
{
  io.digitalWrite(ledGreen, HIGH);
}
void blueOn()
{
  io.digitalWrite(ledBlue, LOW);
}
void blueOff()
{
  io.digitalWrite(ledBlue, HIGH);
}
```

After uploading the code, open the [Serial Monitor](https://learn.sparkfun.com/tutorials/terminal-basics) or terminal emulator of your choice with the baud rate set to **115200**. Press down on any of the buttons. You will notice a serial output indicating which button was pressed in the Arduino Serial Monitor. Looking to the board, you will notice the LED changing color with respect to the button press.

<div style="text-align: center;">
  <table>
    <tr style="vertical-align:middle;">
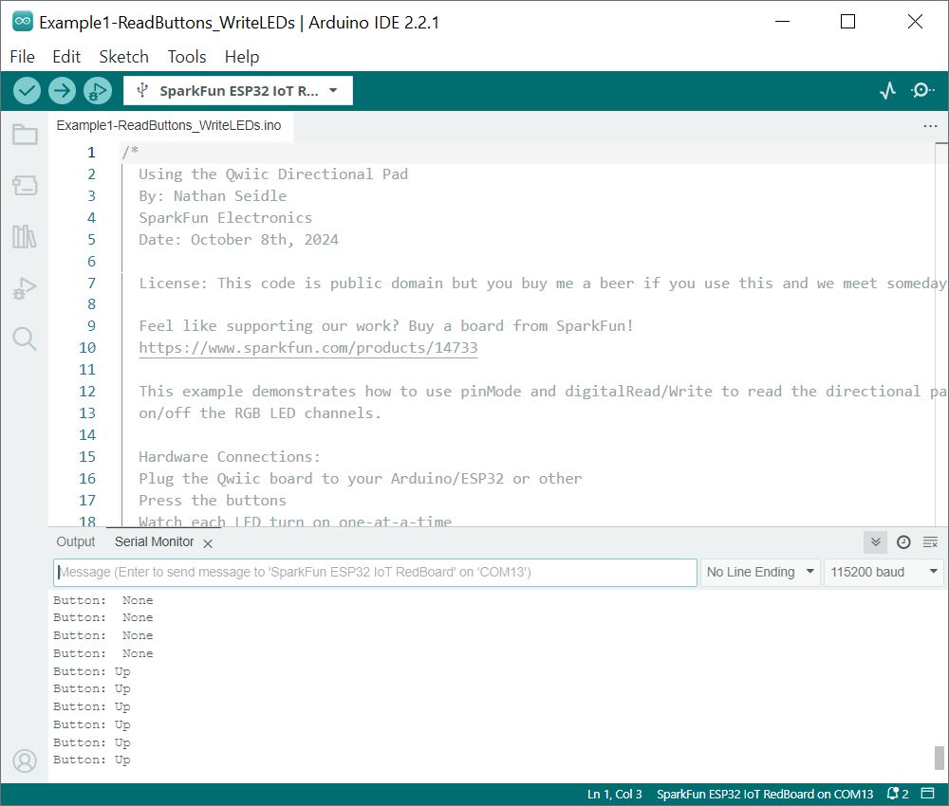
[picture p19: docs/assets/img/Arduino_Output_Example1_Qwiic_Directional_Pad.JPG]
Arduino Serial Output
     <td style="text-align: center; vertical-align: middle; border: solid 1px #cccccc;"></td>
    </tr>
    <tr style="vertical-align:middle;">
     <td style="text-align: center; vertical-align: middle; border: solid 1px #cccccc;"><i>Arduino Example 1 Serial Output</i></td>
    </tr>
  </table>
</div>

### Example 2: Interrupt Pin

!!! note
    Example 3 from the SparkFun I2C Expander Arduino Library uses the IoT RedBoard - ESP32's pin `14` for the interrupt. The example in this tutorial is slightly different and uses pin `4` for the interrupt.

From your downloads, open the example labeled as **Example2_InterruptReadButtons_WriteLEDs.ino**. This example reads the button presses and writes to the non-addressable LED whenever there is an interrupt using the PCA9554 I/O I<sup>2</sup>C Expander. Make sure to connect the Qwiic Directional Pad's interrupt pin to the IoT RedBoard's pin `4`.

For users using an Arduino microcontroller, select your board in the Tools menu (in our case the **SparkFun ESP32 IoT RedBoard**) and the correct Port it enumerated on.

You can also copy or paste the code as shown below. Then click "Upload".

``` c++
/*
  Using the PCA9554 with Interrupts
  Modified by: Ho Yun "Bobby" Chan
  Orignally Written By: Nathan Seidle
  SparkFun Electronics
  Date: November 22nd, 2024

  License: This code is public domain but you buy me a beer if you use this and we meet someday (Beerware license).

  Feel like supporting our work? Buy a board from SparkFun!
  https://www.sparkfun.com/products/17047 - Qwiic GPIO
  https://www.sparkfun.com/products/26784 - Qwiic Power Switch
  https://www.sparkfun.com/products/26851 - Qwiic Directional Pad

  This example demonstrates how to use interrupts to check for new pin changes on the Qwiic Directional Pad
  and turn on/off the RGB LED channels

  Hardware Connections:
  Plug the Qwiic Directional Pad into a Qwiic enabled board (SparkFun Thing Plus C, RedBoard, RedBoard IoT, etc)
  If you don't have a platform with a Qwiic connection use the SparkFun Qwiic Breadboard Jumper (https://www.sparkfun.com/products/17912)
  Connect a wire from a GPIO pin that is interrupt capable to the !INT pin on the Qwiic Directional Pad
  Open the serial monitor at 115200 baud to see the output.
*/

#include <SparkFun_I2C_Expander_Arduino_Library.h>  // Click here to get the library: http://librarymanager/All#SparkFun_I2C_Expander_Arduino_Library

//SFE_PCA95XX io(PCA95XX_PCA9534); // Create a PCA9534 - Has interrupt pin
//SFE_PCA95XX io(PCA95XX_PCA9536); // Create a PCA9536 - Has optional interrupt pin
//SFE_PCA95XX io(PCA95XX_PCA9537); // Create a PCA9537 - Has interrupt pin
SFE_PCA95XX io(PCA95XX_PCA9554);  // Create a PCA9554 - Has interrupt pin
//SFE_PCA95XX io(PCA95XX_PCA9556); // Create a PCA9556 - No interrupt pin / Not compatible with this code
//SFE_PCA95XX io(PCA95XX_PCA9557); // Create a PCA9557 - No interrupt pin / Not compatible with this code

int buttonUp = 0;
int buttonDown = 1;
int buttonRight = 2;
int buttonLeft = 3;
int buttonCenter = 4;
int ledBlue = 5;
int ledGreen = 6;
int ledRed = 7;

int gpioExpander_interrupt = 4;  //INT of PCA9554 is connected to ESP pin 4. Goes low when an input pin changes.

bool buttonPressed = false;

//Interrupt that is called when INT pin goes low
void IRAM_ATTR gpioExpanderISR() {
  buttonPressed = true;
}

void setup() {
  Serial.begin(115200);
  delay(250);
  Serial.println("Qwiic Directional Pad Example");

  Wire.begin();

  // Initialize the PCA95xx with its default I2C address
  if (io.begin() == false) {
    Serial.println("PCA9554 not detected. Please check wiring. Freezing...");
    while (1)
      ;
  }
  pinMode(gpioExpander_interrupt, INPUT_PULLUP);

  io.pinMode(buttonUp, INPUT);
  io.pinMode(buttonDown, INPUT);
  io.pinMode(buttonLeft, INPUT);
  io.pinMode(buttonRight, INPUT);
  io.pinMode(buttonCenter, INPUT);
  io.pinMode(ledRed, OUTPUT);
  io.pinMode(ledGreen, OUTPUT);
  io.pinMode(ledBlue, OUTPUT);

  redOff();
  greenOff();
  blueOff();

  Serial.println("Qwiic Directional Pad online!");

  attachInterrupt(gpioExpander_interrupt, gpioExpanderISR, CHANGE);
}

void loop() {
  //Wait for interrupt to fire
  if (buttonPressed == true) {
    Serial.println("Interrupt! ");
    //Get all the pins in one read to save time
    uint8_t currentState = io.getInputRegister();
    // Pins are pulled high so when we see low, button is being pressed
    if ((currentState & (1 << buttonUp)) == 0) {
      Serial.println("Up");

      //RED
      redOn();
      greenOff();
      blueOff();
    } else if ((currentState & (1 << buttonDown)) == 0) {
      Serial.println("Down");

      //GREEN
      redOff();
      greenOn();
      blueOff();
    } else if ((currentState & (1 << buttonLeft)) == 0) {
      Serial.println("Left");

      //MAGENTA
      redOn();
      greenOff();
      blueOn();
    } else if ((currentState & (1 << buttonRight)) == 0) {
      Serial.println("Right");

      //CYAN
      redOff();
      greenOn();
      blueOn();
    } else if ((currentState & (1 << buttonCenter)) == 0) {
      Serial.println("Center");

      //WHITE
      redOn();
      greenOn();
      blueOn();
    } else {
      Serial.println(" None");

      //OFF
      redOff();
      greenOff();
      blueOff();
    }

    buttonPressed = false;
  }
}

void redOn() {
  io.digitalWrite(ledRed, LOW);
}
void redOff() {
  io.digitalWrite(ledRed, HIGH);
}
void greenOn() {
  io.digitalWrite(ledGreen, LOW);
}
void greenOff() {
  io.digitalWrite(ledGreen, HIGH);
}
void blueOn() {
  io.digitalWrite(ledBlue, LOW);
}
void blueOff() {
  io.digitalWrite(ledBlue, HIGH);
}
```

After uploading the code, open the [Serial Monitor](https://learn.sparkfun.com/tutorials/terminal-basics) or terminal emulator of your choice with the baud rate set to **115200**. Press down on any of the buttons. You will notice a serial output indicating which button was pressed in the Arduino Serial Monitor whenever there is a button press. Looking to the board, you will notice the LED changing color with respect to the button press.

<div style="text-align: center;">
  <table>
    <tr style="vertical-align:middle;">
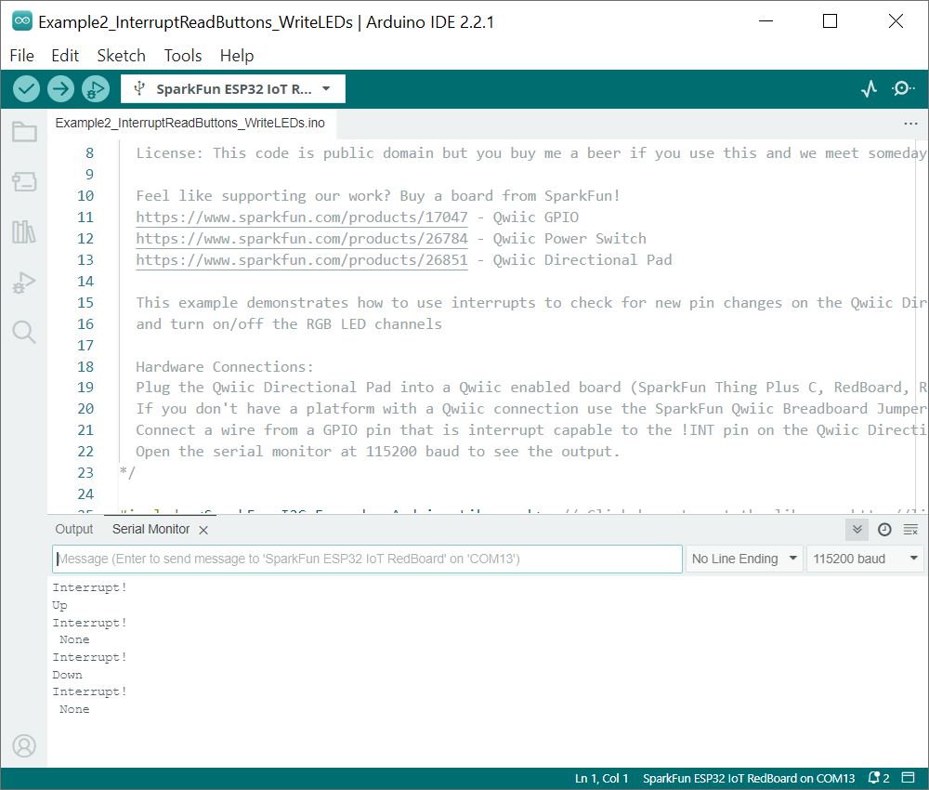
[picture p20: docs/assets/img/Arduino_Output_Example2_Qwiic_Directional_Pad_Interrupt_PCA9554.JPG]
Arduino Serial Output
     <td style="text-align: center; vertical-align: middle; border: solid 1px #cccccc;"></td>
    </tr>
    <tr style="vertical-align:middle;">
     <td style="text-align: center; vertical-align: middle; border: solid 1px #cccccc;"><i>Arduino Example 2 Serial Output</i></td>
    </tr>
  </table>
</div>

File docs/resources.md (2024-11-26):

Now that you've successfully got your SparkFun Qwiic Directional Pad up and running, it's time to incorporate it into your own project! For more information, check out the resources below:

* [Schematic (PDF)](../assets/board_files/SparkFun_Qwiic_Directional_Pad_Schematic_v1_1.pdf)
* [KiCad Files (ZIP)](../assets/board_files/SparkFun_Qwiic_Directional_Pad_v1_1.zip)
* [3D Model (STEP)](../assets/3d_model/SparkFun_Qwiic_Directional_Pad_3D_Model.step)
* [Board Dimensions (PNG)](../assets/img/SparkFun_Qwiic_Directional_Pad-User_Board_Dimensions.png)
* Component Datasheets
    * [K1-1210UN Directional Pad](../assets/component_documentation/Korean-Hroparts-Elec-K1-1210UN.pdf)
    * [PCA9554](../assets/component_documentation/pca9554.pdf)
* [Arduino Library](https://github.com/sparkfun/SparkFun_I2C_Expander_Arduino_Library)
* [Arduino Example Code](https://github.com/sparkfun/SparkFun_Qwiic_Directional_Pad/blob/main/Firmware/Example1-ReadButtons/Example1-ReadButtons.ino)
* [GitHub Hardware Repo](https://github.com/sparkfun/SparkFun_Qwiic_Directional_Pad/)

Or check out the Qwiic Button or Qwiic Joystick for more ideas!

<div class="grid cards col-4" markdown>
<!-- ----------WHITE SPACE BETWEEN GRID CARDS---------- -->
-   <a href="https://learn.sparkfun.com/tutorials/sparkfun-qwiic-button-hookup-guide">
      <figure markdown>
        SparkFun Qwiic Button Hookup Guide
      </figure>
    </a>

    ---

    <a href="https://learn.sparkfun.com/tutorials/sparkfun-qwiic-button-hookup-guide">
      <b>SparkFun Qwiic Button Hookup Guide</b>
    </a>
<!-- ----------WHITE SPACE BETWEEN GRID CARDS---------- -->
-   <a href="https://learn.sparkfun.com/tutorials/qwiic-joystick-hookup-guide">
      <figure markdown>
        Qwiic Joystick Hookup Guide
      </figure>
    </a>

    ---

    <a href="https://learn.sparkfun.com/tutorials/qwiic-joystick-hookup-guide">
      <b>Qwiic Joystick Hookup Guide</b>
    </a>
<!-- ----------WHITE SPACE BETWEEN GRID CARDS---------- -->
</div>

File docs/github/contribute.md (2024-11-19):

# Contribute: Help Fix our Mistake!
Spot something wrong? Feel free to contribute our open-source design and documentation. 

## Improve our Documentation
All of this documentation can be modified by you! Please help us make it better.

* These pages are contained in the [`docs` folder of the SparkFun Qwiic Directional Pad repository](https://github.com/sparkfun/SparkFun_Qwiic_Directional_Pad/tree/main/docs).

### Submit a Correction
1. Fork this repo
2. Add your corrections or improvements to the markdown file
3. File a pull request with your changes, and enjoy making the ~~words~~ ~~worlds~~ world a better place.
    * Once received, the documentation specialist will automatically be notified.
    * We will review your suggested improvements to make sure they are correct and fit within our documentation standards.

## Improve our Hardware Design
All of our designs are open-source! Please help us make it better.

* Our board design files are contained in the [`Hardware` folder of the SparkFun Qwiic Directional Pad repository](https://github.com/sparkfun/SparkFun_Qwiic_Directional_Pad/tree/main/Hardware).

### Submit a Design Improvement
1. Fork this repo
2. Add your design improvements
3. File a pull request with your changes, and enjoy making the ~~words~~ ~~worlds~~ world a better place.
    * Once received, the engineer in charge of the original design will automatically be notified.
    * We will review your suggested improvements, if they are within our board design standards and meet our product design requirements, we will flag these changes for our next board revision. *(Please note, that even if your suggestion is accepted, these changes may not be immediate. We may have to cycle through our current product inventory first.)*

## Contributors
Let's provided some recognition to the contributors for this project!

GitHub Contributors Image
<br>


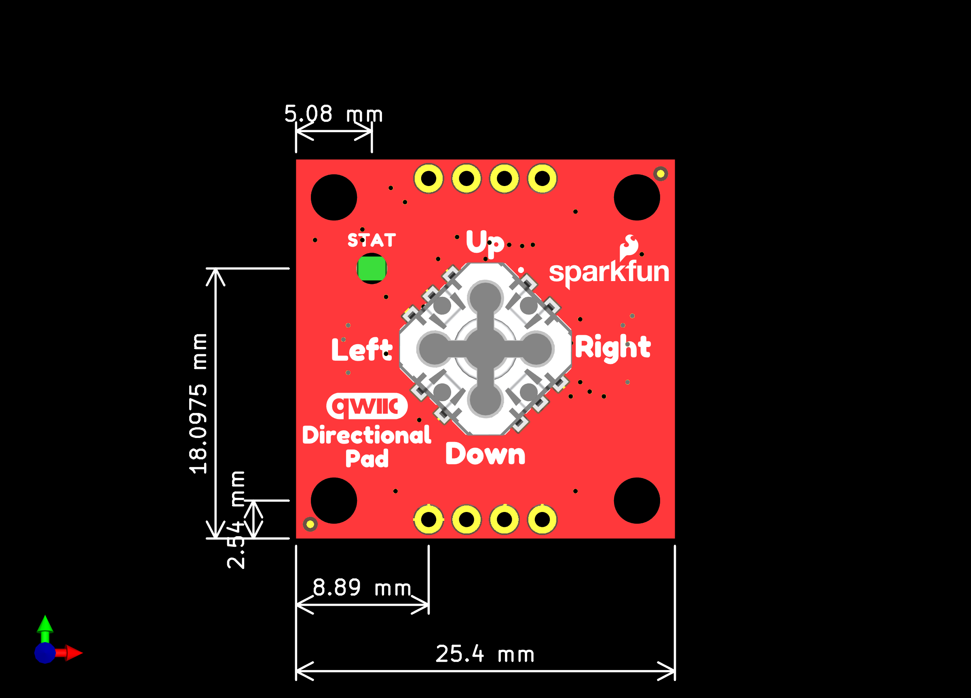
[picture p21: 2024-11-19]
docs/assets/3d_model/SparkFun_Qwiic_Directional_Pad_3D_Image.png

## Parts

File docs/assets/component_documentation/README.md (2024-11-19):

SparkFun Documentation
=======================

This directory should include any necessary datasheets, example number crunching, etc.

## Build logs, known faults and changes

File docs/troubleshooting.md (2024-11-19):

### General Troubleshooting Help

!!! note
    <span class="glyphicon glyphicon-question-sign" aria-hidden="true"></span>
        <strong> Not working as expected and need help? </strong> <br /><br />

    If you need technical assistance and more information on a product that is not working as you expected, we recommend heading on over to the <a href="https://www.sparkfun.com/technical_assistance">SparkFun Technical Assistance</a> page for some initial troubleshooting. <br /><br />

    <div style="text-align: center"><a href="https://www.sparkfun.com/technical_assistance" target="sfe_technical_assistance" class="md-button">SparkFun Technical Assistance Page</a></div>

    If you don't find what you need there, the <a href="https://community.sparkfun.com/">SparkFun Forums</a> are a great place to find and ask for help. If this is your first visit, you'll need to create a forum account to search product forums and post questions.<br /><br />

    <div style="text-align: center"><a href="https://community.sparkfun.com/" class="md-button md-button--primary">Log Into SparkFun Forums</a></div>

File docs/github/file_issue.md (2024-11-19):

# Did we make a mistake?

Spot something wrong? Please let us know. 

!!! attention
    This is not where customers should seek assistance on a product. If you require technical assistance or have questions about a product that is not working as expected, please head over to the [SparkFun Technical Assistance](https://www.sparkfun.com/technical_assistance) page for some initial troubleshooting.
    <center>
    [SparkFun Technical Assistance Page](https://www.sparkfun.com/technical_assistance){ .md-button .md-button--primary }
    </center>

    If you can't find what you need there, you'll need a [Forum Account](https://forum.sparkfun.com/ucp.php?mode=register) to search product forums and post questions.

## Discrepancies in the Documentation

All of this documentation can be modified by you! Please help us make it better.

* The documentation files for these pages are contained in the [`docs` folder of the SparkFun Qwiic Directional Pad repository](https://github.com/sparkfun/SparkFun_Qwiic_Directional_Pad/tree/main/docs).

### Spot something wrong?
If a section of the documentation is incorrect, please [open an issue](https://github.com/sparkfun/SparkFun_Qwiic_Directional_Pad/issues) and let us know.

### Do you have a suggested correction?
1. With a GitHub account, fork this repo
2. Add your correction(s) or improvement(s) to the markdown file(s)
3. File a pull request with your changes, and enjoy making the ~~words~~ ~~worlds~~ world a better place.
    * Once received, the documentation specialist will automatically be notified.
    * We will review your suggested improvement(s) to make sure they are correct and fit within our documentation standards.

## Problems in the Hardware Design

All of our designs are open-source! Please help us make it better.

* Our board design files are contained in the [`Hardware` folder of the SparkFun Qwiic Directional Pad repository](https://github.com/sparkfun/SparkFun_Qwiic_Directional_Pad/tree/main/Hardware).

### Does something not make sense?
If part of the design is confusing, please [open an issue](https://github.com/sparkfun/SparkFun_Qwiic_Directional_Pad/issues) and let us know.

### Did we forget to include an important function of the board?
* Please keep in mind that we may intentionally exclude certain functions of the board to meet our product design requirements. *(For example, our Qwiic Micro boards are intended to fit on a small board layout and only use I<sup>2</sup>C communication; therefore, we may not have the SPI and interrupt pins available for users.)*
* If part of the board's functionality is missing, please [open an issue](https://github.com/sparkfun/SparkFun_Qwiic_Directional_Pad/issues) and file a feature request.

### Do you wish to contribute directly to improving the board design?
1. With a GitHub account, Fork this repo
2. Add your design improvement(s)
3. File a pull request with your changes, and enjoy making the ~~words~~ ~~worlds~~ world a better place.
    * Once received, the engineer in charge of the original design will automatically be notified.
    * We will review your suggested improvement(s), if they are within our board design standards and meet our product design requirements, we will flag these changes for our next board revision. *(Please note, that even if your suggestion is accepted, these changes may not be immediate. We may have to cycle through our current product inventory first.)*

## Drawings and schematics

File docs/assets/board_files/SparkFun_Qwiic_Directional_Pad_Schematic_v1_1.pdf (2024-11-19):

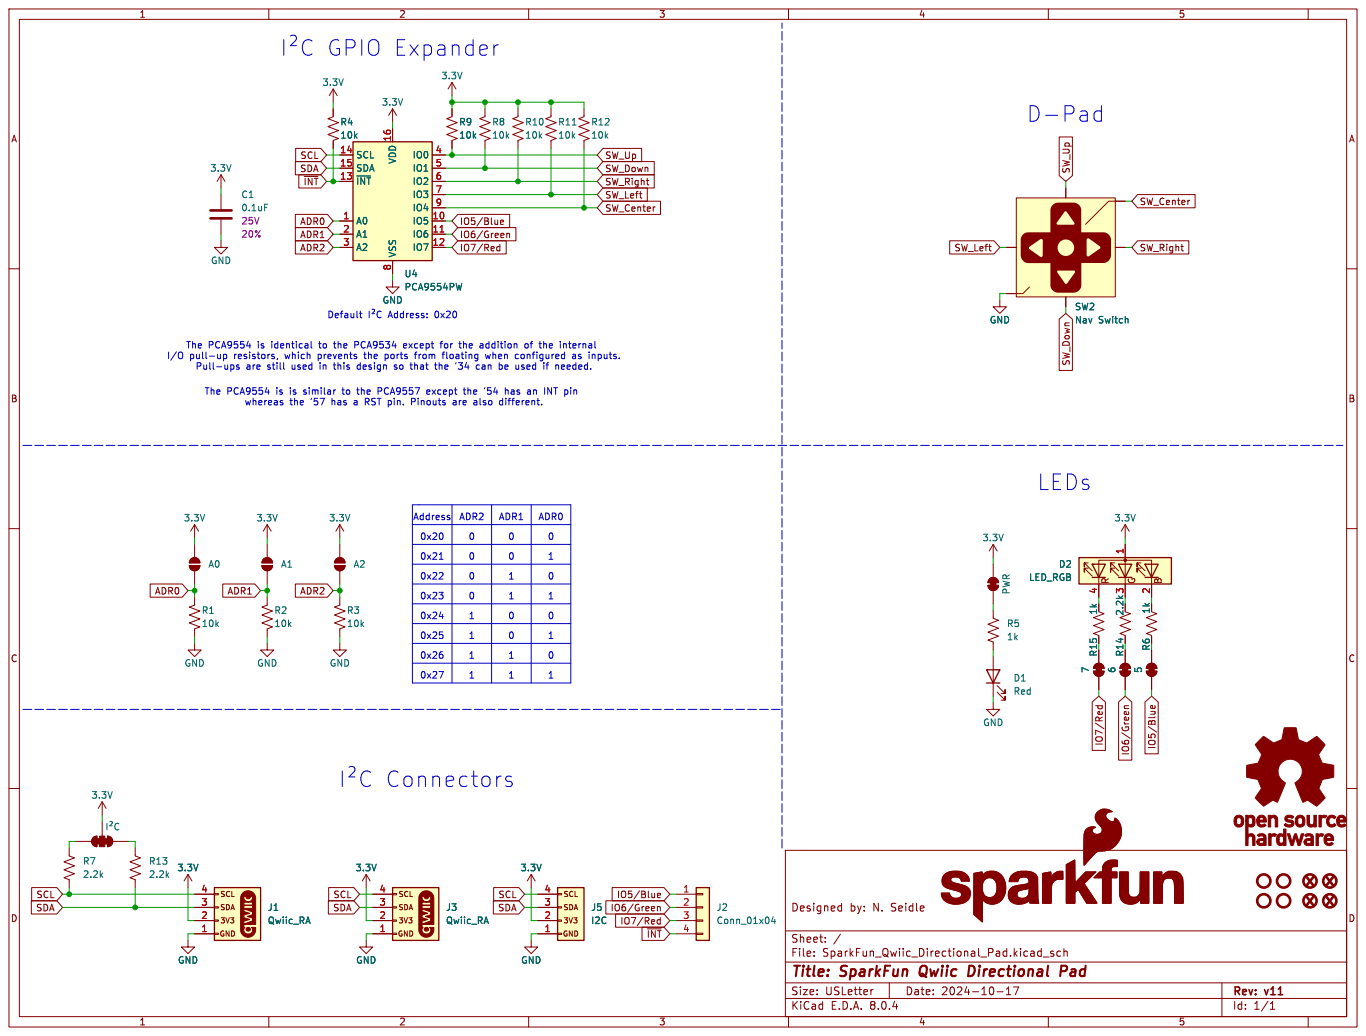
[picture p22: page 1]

IO6/Green~{INT} SCL SDA

Id: 1/1 Title: SparkFun Qwiic Directional Pad

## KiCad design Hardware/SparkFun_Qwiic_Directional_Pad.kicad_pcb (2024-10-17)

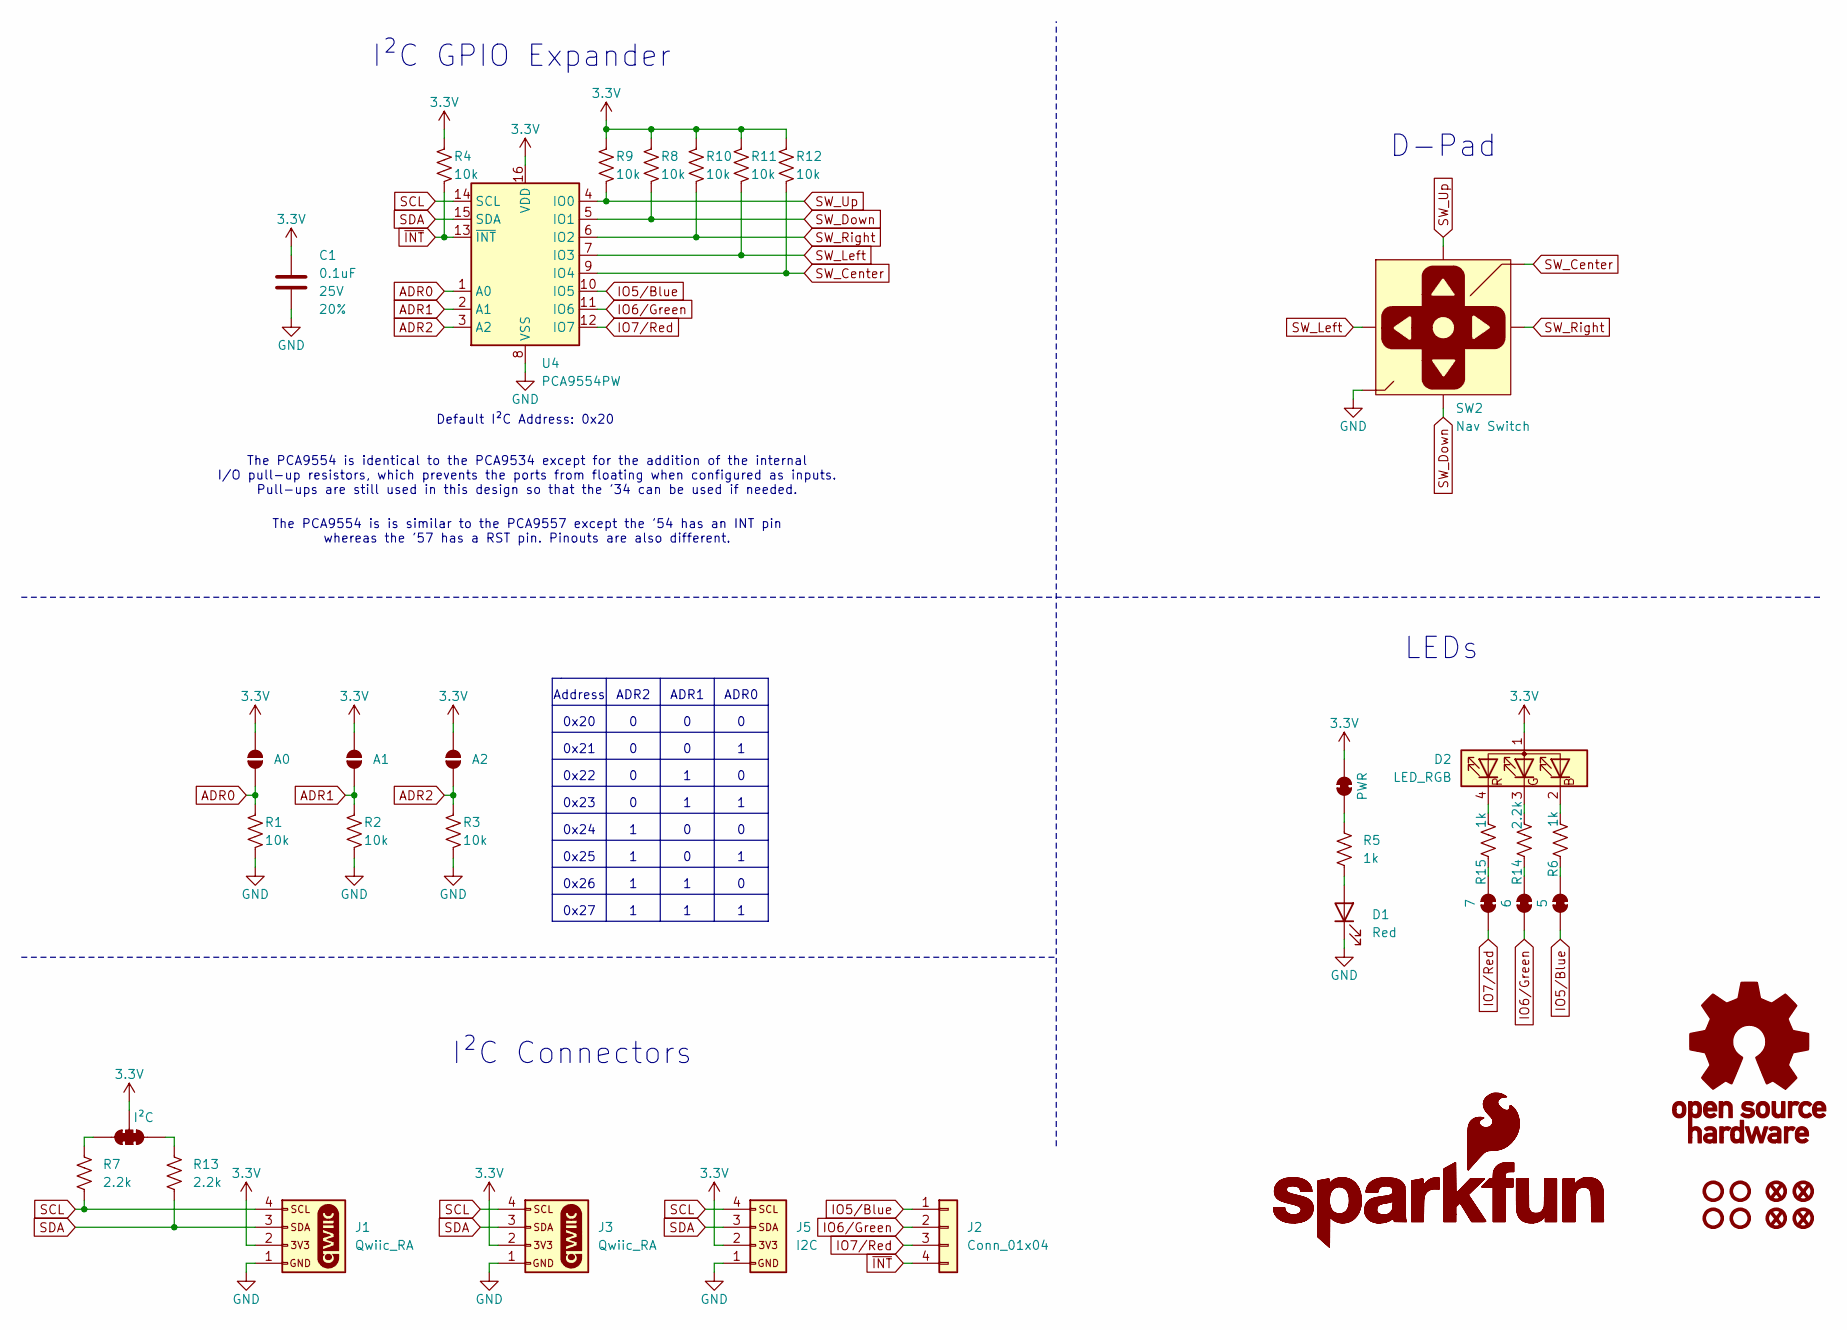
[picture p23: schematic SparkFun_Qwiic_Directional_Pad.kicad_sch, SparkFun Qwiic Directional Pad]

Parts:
C1: 0.1uF; C_0603_1608Metric; Voltage 25V; Tolerance 20%
D1: Red; LED_0603_1608Metric_Red
D2: LED_RGB; LED_1205_RGB_Bottom
FID1, FID2, FID3, FID4: Fiducial_0.5mm; Fiducial_0.5mm_Mask1mm
G1: OSHW_Logo; Creative_Commons_License
G3: SparkFun_Logo
G5: SparkFun_Logo; SparkFun_Logo_8mm
J1, J3: Qwiic_RA; JST_SMD_1.0mm-4_RA
J2: Conn_01x04; 1x04
J5: I2C; 1x04
JP1: A0; Jumper_2_NO
JP2: A1; Jumper_2_NO
JP3: A2; Jumper_2_NO
JP4: PWR; Jumper_2_NC_Trace
JP5: 5; Jumper_2_NC_Trace
JP6: I²C; Jumper_3_NC-2_Trace
JP7: 6; Jumper_2_NC_Trace
JP8: 7; Jumper_2_NC_Trace
R1, R2, R3, R4, R8, R9, R10, R11, R12: 10k; R_0603_1608Metric
R5, R6, R15: 1k; R_0603_1608Metric
R7, R13, R14: 2.2k; R_0603_1608Metric
ST1, ST2, ST3, ST4: Standoff
SW2: Nav Switch; Navigation_SMD_9.9x9.9mm
U4: PCA9554PW; TSSOP-16_4.4x5mm_P0.65mm

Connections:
3.3V: C1.1, D2.1 (A), J1.2, J3.2, J5.2, JP1.2 (B), JP2.2 (B), JP3.2 (B), JP4.2 (B), JP6.2 (C), R4.2, R8.2, R9.2, R10.2, R11.2, R12.2, U4.16 (VDD)
ADR0: JP1.1 (A), R1.2, U4.1 (A0)
ADR1: JP2.1 (A), R2.2, U4.2 (A1)
ADR2: JP3.1 (A), R3.2, U4.3 (A2)
GND: C1.2, D1.1 (K), J1.1, J3.1, J5.1, R1.1, R2.1, R3.1, SW2.3 (GND), SW2.6 (GND), SW2.8 (GND), SW2.9 (GND), SW2.10 (GND), U4.8 (VSS)
IO5/Blue: J2.1, JP5.2 (B), U4.10 (IO5)
IO6/Green: J2.2, JP7.2 (B), U4.11 (IO6)
IO7/Red: J2.3, JP8.2 (B), U4.12 (IO7)
unnamed: D1.2 (A), R5.2
unnamed: D2.2 (BK), R6.2
unnamed: D2.3 (GK), R14.2
unnamed: D2.4 (RK), R15.2
unnamed: JP4.1 (A), R5.1
unnamed: JP5.1 (A), R6.1
unnamed: JP6.1 (A), R13.1
unnamed: JP6.3 (B), R7.1
unnamed: JP7.1 (A), R14.1
unnamed: JP8.1 (A), R15.1
SCL: J1.4, J3.4, J5.4, R7.2, U4.14 (SCL)
SDA: J1.3, J3.3, J5.3, R13.2, U4.15 (SDA)
SW_Center: R12.1, SW2.4 (Center), U4.9 (IO4)
SW_Down: R8.1, SW2.5 (Down), U4.5 (IO1)
SW_Left: R11.1, SW2.7 (Left), U4.7 (IO3)
SW_Right: R10.1, SW2.2 (Right), U4.6 (IO2)
SW_Up: R9.1, SW2.1 (Up), U4.4 (IO0)
~INT: J2.4, R4.1, U4.13 (~INT)

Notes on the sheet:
The PCA9554 is is similar to the PCA9557 except the '54 has an INT pin whereas the '57 has a RST pin. Pinouts are also different.
Default I²C Address: 0x20
I²C GPIO Expander
0x20
I²C Connectors
ADR2
ADR0
0x23
The PCA9554 is identical to the PCA9534 except for the addition of the internal I/O pull-up resistors, which prevents the ports from floating when configured as inputs. Pull-ups are still used in this design so that the '34 can be used if needed.
0x22
LEDs
0x25
0x26
0x24
D-Pad
0x27
ADR1
0x21
Address

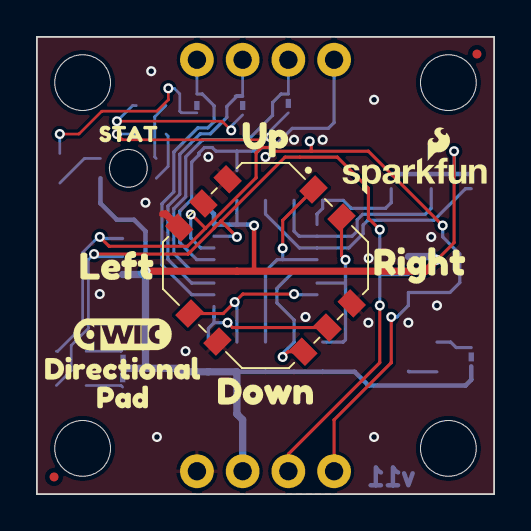
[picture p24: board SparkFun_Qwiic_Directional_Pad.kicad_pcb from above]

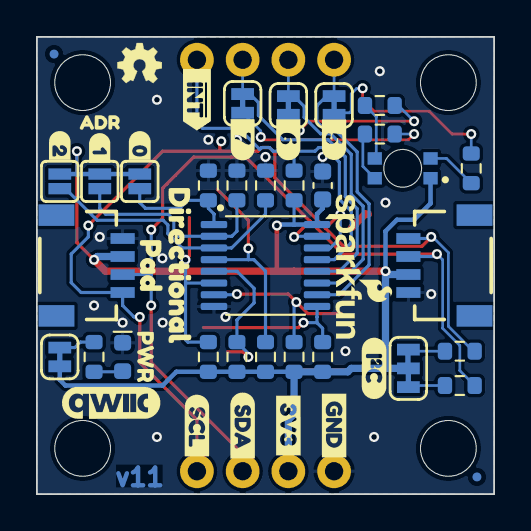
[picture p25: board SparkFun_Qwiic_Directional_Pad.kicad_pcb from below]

Board: 2 copper layers, 25.4 x 25.4 mm, 65 parts (48 on the bottom side), 26 nets.

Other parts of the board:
Ref**: Val**; OSHW_Logo_2.5mm
kibuzzard-64C2E6A3: G***; kibuzzard-64C2E6A3
kibuzzard-66EED5D2: G***; kibuzzard-66EED5D2
kibuzzard-66EF6B89: G***; kibuzzard-66EF6B89
kibuzzard-66EF7A0B: G***; kibuzzard-66EF7A0B
kibuzzard-66EF7A03: G***; kibuzzard-66EF7A03
kibuzzard-66EF7A24: G***; kibuzzard-66EF7A24
kibuzzard-66EF7AE6: G***; kibuzzard-66EF7AE6
kibuzzard-66EF7AEF: G***; kibuzzard-66EF7AEF
kibuzzard-66EF7B1E: G***; kibuzzard-66EF7B1E
kibuzzard-66EF7B7C, kibuzzard-66EF7B7C#2: G***; kibuzzard-66EF7B7C
kibuzzard-66EF7B15: G***; kibuzzard-66EF7B15
kibuzzard-66EF7B78, kibuzzard-66EF7B78#2: G***; kibuzzard-66EF7B78
kibuzzard-66EF55AC: G***; kibuzzard-66EF55AC
kibuzzard-66EF79E9: G***; kibuzzard-66EF79E9
kibuzzard-66EF559E: G***; kibuzzard-66EF559E
kibuzzard-66EF5597: G***; kibuzzard-66EF5597
kibuzzard-66F18F5E: G***; kibuzzard-66F18F5E
kibuzzard-66F18F8F: G***; kibuzzard-66F18F8F
kibuzzard-66F18F9B: G***; kibuzzard-66F18F9B
kibuzzard-66F182A6: G***; kibuzzard-66F182A6
kibuzzard-67117BDD: G***; kibuzzard-67117BDD

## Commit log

2024-09-23 Add ignore
    [SparkFun_Qwiic_Directional_Pad.kicad_pcb, SparkFun_Qwiic_Directional_Pad.kicad_sch]
2024-09-23 Fix page names.
    [SparkFun_Qwiic_Directional_Pad.kicad_pcb, SparkFun_Qwiic_Directional_Pad.kicad_sch]
2024-09-23 Add DRC exclusions
    [SparkFun_Qwiic_Directional_Pad.kicad_pcb]
2024-09-23 Switch to RGB 1205 rear mount LED
    [SparkFun_Qwiic_Directional_Pad.kicad_pcb, SparkFun_Qwiic_Directional_Pad.kicad_sch]
2024-10-08 Switch to PCA9554
    [SparkFun_Qwiic_Directional_Pad.kicad_pcb, SparkFun_Qwiic_Directional_Pad.kicad_sch]
2024-10-17 Switch to PCA9554 with INT pin
    [SparkFun_Qwiic_Directional_Pad.kicad_pcb, SparkFun_Qwiic_Directional_Pad.kicad_sch]
2024-10-17 Update jumper names, I2C address table.
    [SparkFun_Qwiic_Directional_Pad.kicad_pcb, SparkFun_Qwiic_Directional_Pad.kicad_sch]
2024-11-21 Add More Content
    - Introduction
    - Hardware Overview
    - Hardware Hookup
    - Arduino Library
    - Tutorial Photos
2024-11-22 Add Arduino Example, Fix Typos, & Remove Artifacts from Cloned Tutorial
2024-11-22 Fix Typos and Add Interrupt Example
    [Example2_InterruptRead_Output_LEDs.ino]
2024-11-27 Add Note about Interrupt Pin

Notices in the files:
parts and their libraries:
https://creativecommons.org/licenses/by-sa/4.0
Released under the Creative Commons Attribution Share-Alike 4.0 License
